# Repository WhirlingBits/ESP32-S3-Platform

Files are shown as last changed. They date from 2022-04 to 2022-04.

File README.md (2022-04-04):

# ESP_Platform_Schematic

## Description
Schematics of basic ESP32-S3-WROOM platform with versatile power management
for 12V and 5V supply and microSD card slot.
The board offers 2 USB-C receptables, one connecting to a USB-2-UART converter
(CP2102) feeding the genuine UART0 on ESP32-S3 and another directly connecting
to the ESP32-S3's USB OTG port.

## Power Management
The board may be powered by one of the USB ports (VBUS) or with an external
power supply connected via BarrelJack. So altogether there are 3 possible sources of
power, USB (PGM), USB (Data) and Ext. To prevent any currents flowing from the
source with higher voltage to a source with lower voltage Schotty diodes with
low treshold have been implemented.

Thanx to the buck/boost capability of the LTC3111 used the external power input
voltage may supply a voltage between 3..15V.

Alternatively it is possible to use an external battery controller (e.g. Sparkfun
Babysitter) which is connected on J5 whereas J5.4 (+5VD) will be the input for the
controller and J5.1,2 the output.

## Wifi/BT module from Espressif
For the module we have chosen an ESP32-S3-WROOM-1 from Espressif with 8MByte
serial FLASH and 8MByte PSRAM (suffix -N8R8). ESP32-S3 is more powerful than
classical ESP32-D0WD as its using Dual Core Tensilica LX7 with an augmented 
instruction set supporting low level calculations for CNN processing (tinyML).
For precision of all time related processes there's an clock crystal (32kHz)
assembled.

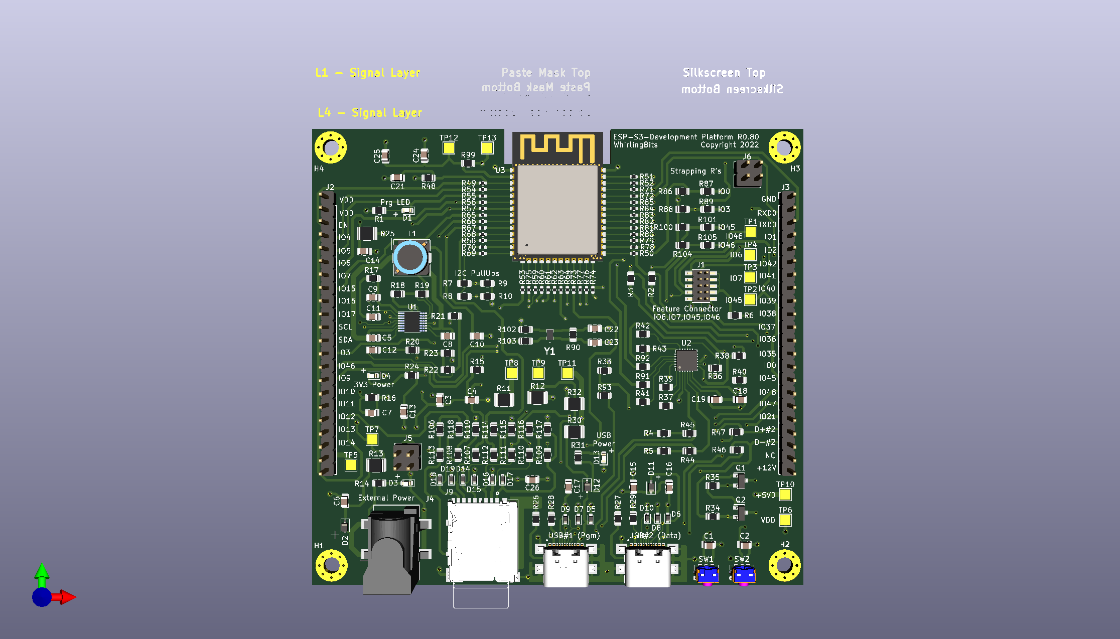
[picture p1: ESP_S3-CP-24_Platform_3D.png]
PCB-3D-View


And this is the real board:
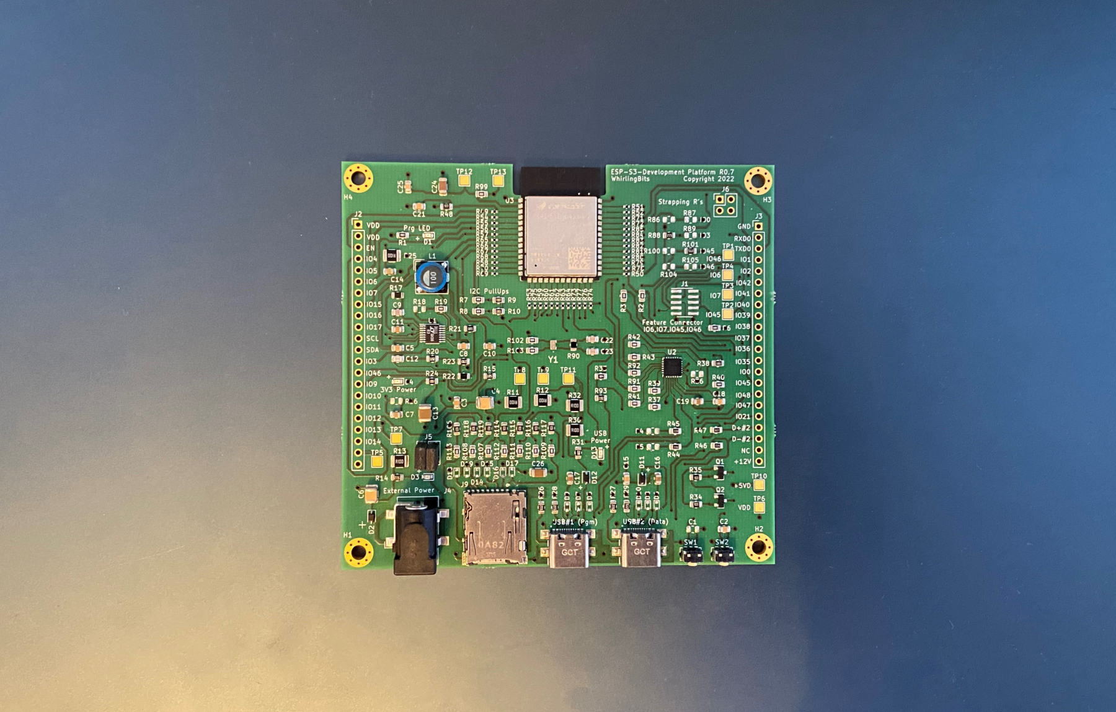
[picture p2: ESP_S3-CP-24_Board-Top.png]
PCB Mounted Board


## CAE System
Schematics and Layout have been developed using KiCAD 5.x version. You may
just download the complete repository to a folder inside your KiCAD project
directories to start using it.

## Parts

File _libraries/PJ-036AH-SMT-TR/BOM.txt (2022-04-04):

3DX_CUI_DEVICES_Supplier: CUI Devices
3DX_CUI_DEVICES_Description: 2.0 x 6.3 mm, 5.0 A, Horizontal, Surface Mount (SMT), Dc Power Jack Connector
3DX_CUI_DEVICES_Model Number: PJ-036AH-SMT-TR

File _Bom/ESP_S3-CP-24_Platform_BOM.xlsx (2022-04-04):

ESP-S3 Developer Platform R0.80 (12.3.2022)
Pos | Sourced | References | Value | Footprint | DigiKey | LCSC | Mouser | Quantity
1 |  | C2, C3, C5, C8, C15, C18, C21, C25 | 0.1uF, 50V | C_0805_2012Metric |  | C161260 |  | 8
2 |  | C7, C10, C14 | 1uF, 16V | C_0805_2012Metric |  | C16834 |  | 3
3 |  | C16, C17, C19 | 4.7uF, 25V | C_0805_2012Metric |  | C98192 |  | 3
4 |  | C4, C6 | 47uF, 22V | C_0805_2012Metric |  | C913559 |  | 2
5 |  | C22, C23 | 12pF, 50V | C_0805_2012Metric |  | C182488 |  | 2
6 |  | C24, C26 | 22uF, 10V | C_0805_2012Metric |  | C77074 |  | 2
7 |  | C1 | 0.1uF, 50V (DNP) | C_0805_2012Metric |  | C161260 |  | 1
8 |  | C9 | 22p | C_0805_2012Metric |  | C105623 |  | 1
9 |  | C11 | 1500p | C_0805_2012Metric |  | C114765 |  | 1
10 |  | C12 | 47p | C_0805_2012Metric |  | C113821 |  | 1
11 |  | C13 | 100uF, 6,3V | C_0805_2012Metric |  | C141660 |  | 1
12 |  | R49, R50, R51, R52, R53, R54, R55, R56, R57, R58, R59, R60, R61, R62, R63, R64, R65, R66, R67, R68, R69, R70, R71, R72, R73, R74, R75, R76, R77, R78, R79, R80, R81, R82, R83, R84, R85 | 22R | R_0402_1005Metric |  | C114765 |  | 37
13 |  | R2, R3, R6, R7, R8, R19, R37, R39, R40, R41, R42, R43, R91, R92, R99, R102, R103, R107, R108, R109, R110, R111, R112, R113 | 0R | R_0805_2012Metric |  | C100045 |  | 24
14 |  | R34, R35, R48, R106, R114, R115, R116, R117, R118, R119 | 10k | R_0805_2012Metric |  | C169253 |  | 10
15 |  | R14, R26, R27, R28, R29, R88, R101 | 5k1 | R_0805_2012Metric |  | C204548 |  | 7
16 |  | R11, R12, R13, R25, R30, R32 | 0R1 | R_1210_3225Metric |  | C473589 |  | 6
17 |  | R86, R87, R89, R100, R104, R105 | 5k1 (DNP) | R_0805_2012Metric |  | C204548 |  | 6
18 |  | R44, R45, R46, R47 | 22R | R_0805_2012Metric |  | C144531 |  | 4
19 |  | R4, R5, R16 | 1M (DNP) | R_0805_2012Metric |  | C230655 |  | 3
20 |  | R9, R10, R38 | 1k | R_0805_2012Metric |  | C95781, |  | 3
21 |  | R1 | 1k8 | R_0805_2012Metric |  | C137465 |  | 1
22 |  | R15 | 1M | R_0805_2012Metric |  | C230655 |  | 1
23 |  | R17 | 41,2k | R_0805_2012Metric |  | C204486 |  | 1
24 |  | R18 | 0R (DNP) | R_0805_2012Metric |  | C100045 |  | 1
25 |  | R20 | 11,5k | R_0805_2012Metric |  | C228269 |  | 1
26 |  | R21 | 49R9 | R_0805_2012Metric |  | C479104 |  | 1
27 |  | R22 | 845k | R_0805_2012Metric |  | C416871 |  | 1
28 |  | R23 | 270k | R_0805_2012Metric |  | C352236 |  | 1
29 |  | R24 | 1k5 | R_0805_2012Metric |  | C163951 |  | 1
30 |  | R31 | 2k2 | R_0805_2012Metric |  | C441982 |  | 1
31 |  | R33 | 47.5k | R_0805_2012Metric |  | C104355 |  | 1
32 |  | R36 | 10k (DNP) | R_0805_2012Metric |  |  |  | 1
33 |  | R90 | 5.6M | R_0805_2012Metric |  | C185285 |  | 1
34 |  | R93 | 22.1k | R_0805_2012Metric |  | C104113 |  | 1
35 |  | L1 | 10uH - SLF7032T-100M1R4-2PF | L_TDK_SLF7032 |  | C76852 |  | 1
36 |  | D5, D6, D7, D8, D9, D10, D14, D15, D16, D17, D18, D19 | PESD15VW1BCSFYL | D_SOD-523 |  |  | 771-PESD15VW1BCSFYL | 12
37 |  | D1, D3, D4, D13 | LTST-C191KRKT (Red) | LED_0603_1608Metric |  | C125099 |  | 4
38 |  | D2, D11, D12 | BAT760-7 | D_SOD-323 |  | C116158 |  | 3
39 |  | U1 | LTC3111EMSEPBF | MSOP-16 |  | C684080 | 584-LTC3111EMSETRPBF | 1
40 |  | U2 | CP2102N-A02-GQFN24 | QFN-24-1EP_4x4mm_P0.5mm_EP2.6x2.6mm |  | C80225 |  | 1
41 |  | U3 | ESP32-S3-WROOM-1 | ESP32-S3-WROOM-1 |  | C2913201 |  | 1
42 |  | Y1 | XTAL 32,678kHz (C20S-12.5PF20PPM) | SC20S125PF20PPM |  | C97603 |  | 1
43 |  | SW1, SW2 | SKRTLAE010 | SW_Push_1P1T-MP_NO_Horizontal_Alps_SKRTLAE010 |  | C110293 |  | 2
44 |  | Q1, Q2 | SS8050-G | SOT-23 |  | C164885 |  | 2
45 |  | J2, J3 | Conn_01x22 (DNP) | PinHeader_1x22_P2.54mm_Vertical |  | C725954 |  | 2
46 |  | J5, J6 | Conn_02x02_Top_Bottom (DNP) | PinHeader_2x02_P2.54mm_Vertical |  | C492419 |  | 2
47 |  | J7, J8 | USB_C_Receptacle (USB4110-GF-A) | GCT_USB4110-GF-A_REVB |  |  | 640-USB4110-GF-A | 2
48 |  | J1 | Conn_02x05_Odd_Even | PinHeader_2x05_P1.27mm_Vertical_SMD |  | C150517 |  | 1
49 |  | J4 | PJ-002AH-SMT-TR (Barrel Jack) | BarrelJack_CLIFF_FC681465S_SMT_Horizontal |  |  | 490-PJ-002AH-SMT-TR | 1
50 |  | J9 | DM3AT-SF-PEJM5 | HRS_DM3AT-SF-PEJM5 |  | C114218 |  | 1

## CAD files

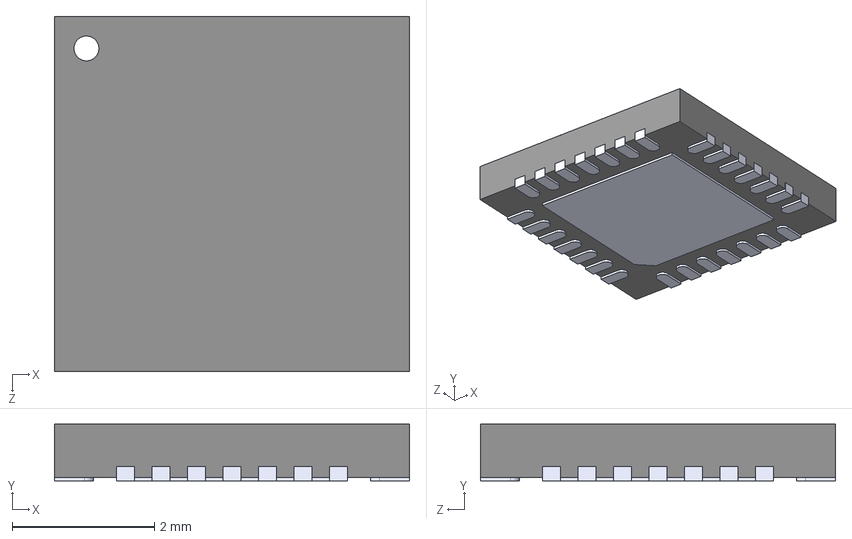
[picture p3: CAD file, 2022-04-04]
_libraries/CP2102N-A01-GQFN28/CP2102N-A01-GQFN28.step
5.00 x 0.8 x 5.00 mm

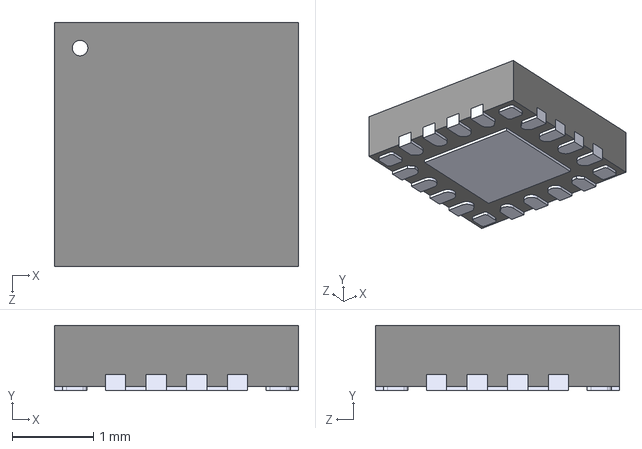
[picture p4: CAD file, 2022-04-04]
_libraries/CP2102N-A02-GQFN20R/CP2102N-A02-GQFN20R.step
3.00 x 0.8 x 3.00 mm

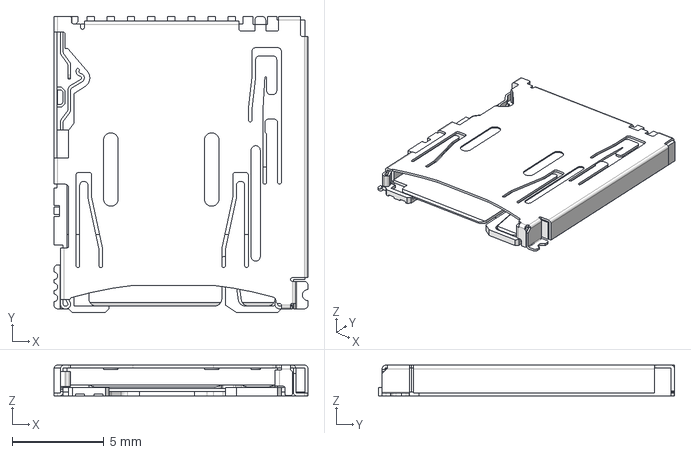
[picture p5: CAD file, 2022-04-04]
_libraries/DM3AT-SF-PEJM5/DM3AT-SF-PEJM5.step
13.8 x 16.2 x 1.68 mm

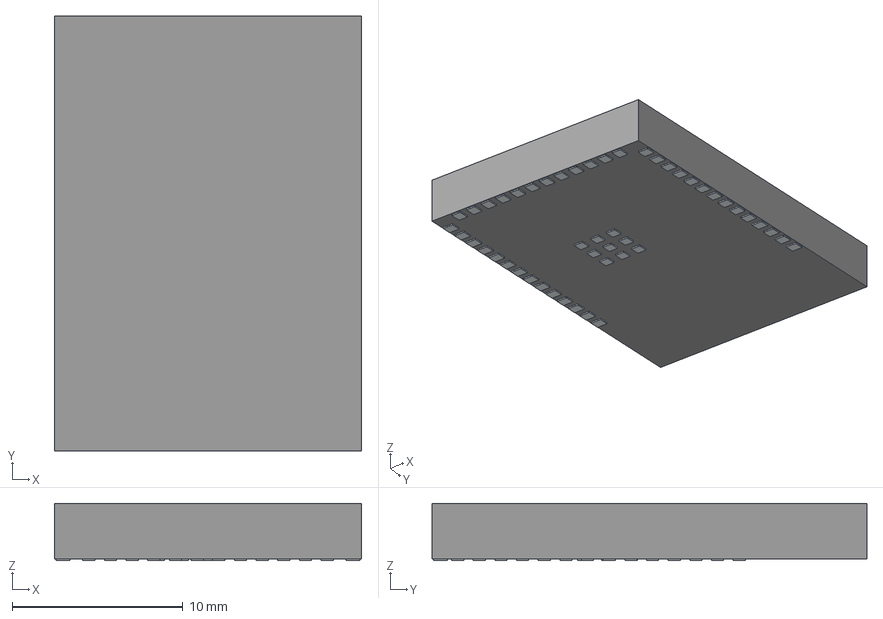
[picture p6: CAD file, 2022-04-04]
_libraries/ESP32-S3-WROOM/ESP32-S3-WROOM-1-N8R2.step
18.0 x 25.5 x 3.35 mm
Pins

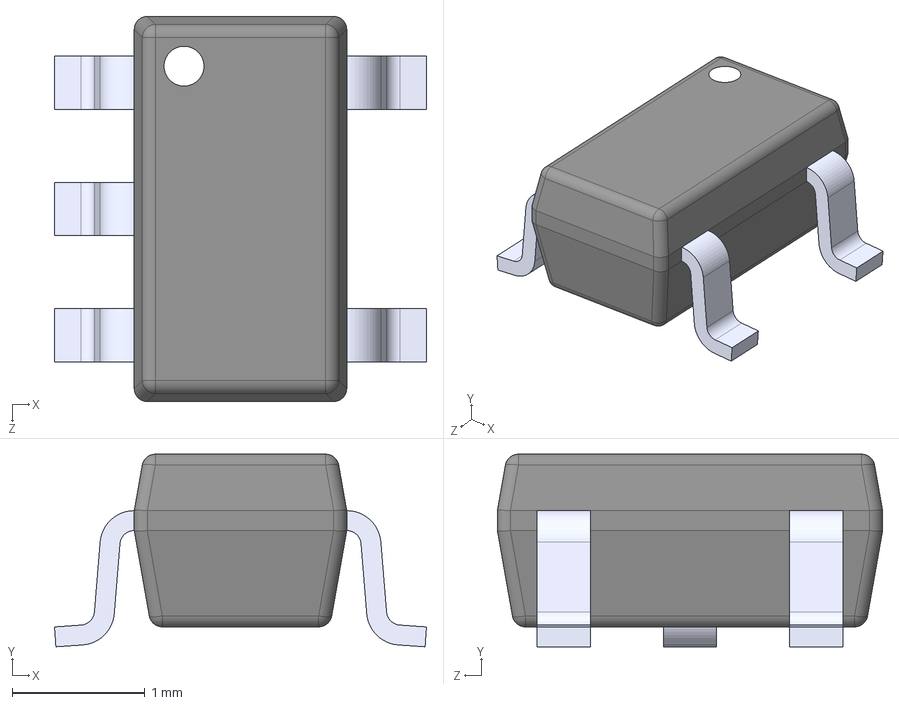
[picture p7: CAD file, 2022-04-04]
_libraries/LM3671MF-3.3/LM3671MF-3.3.step
2.80 x 1.45 x 2.90 mm

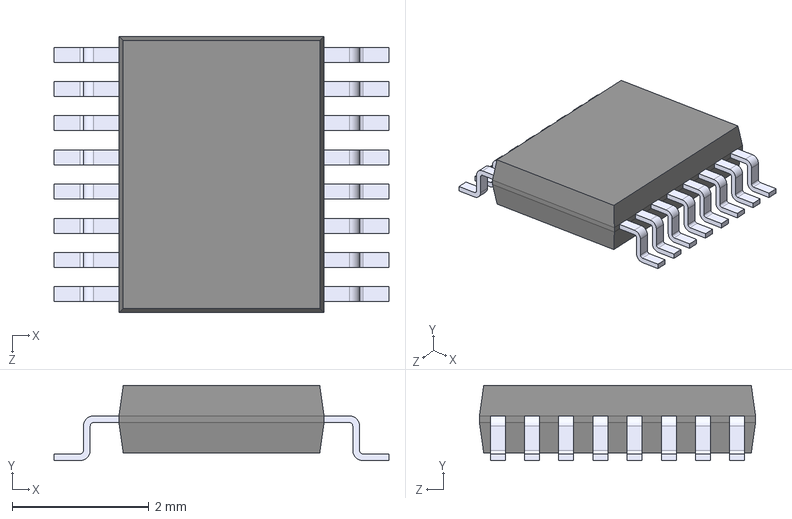
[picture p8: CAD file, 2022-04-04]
_libraries/LTC3111EMSEPBF/LTC3111EMSEPBF.step
4.90 x 1.10 x 4.04 mm

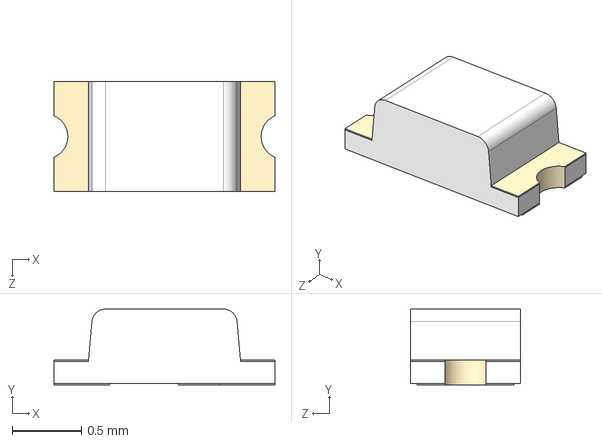
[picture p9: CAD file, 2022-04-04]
_libraries/LTST-C191KGKT/LTST-C191KGKT--3DModel-STEP-56544.STEP
1.60 x 0.55 x 0.8 mm

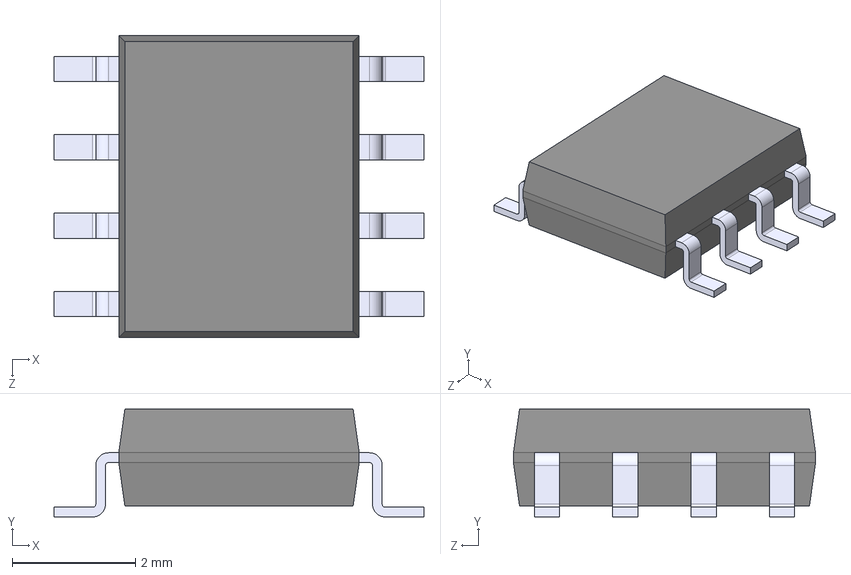
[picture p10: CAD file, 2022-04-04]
_libraries/MIC2026A-1YM-TR/MIC2026A-1YM-TR.step
6.00 x 1.75 x 4.90 mm

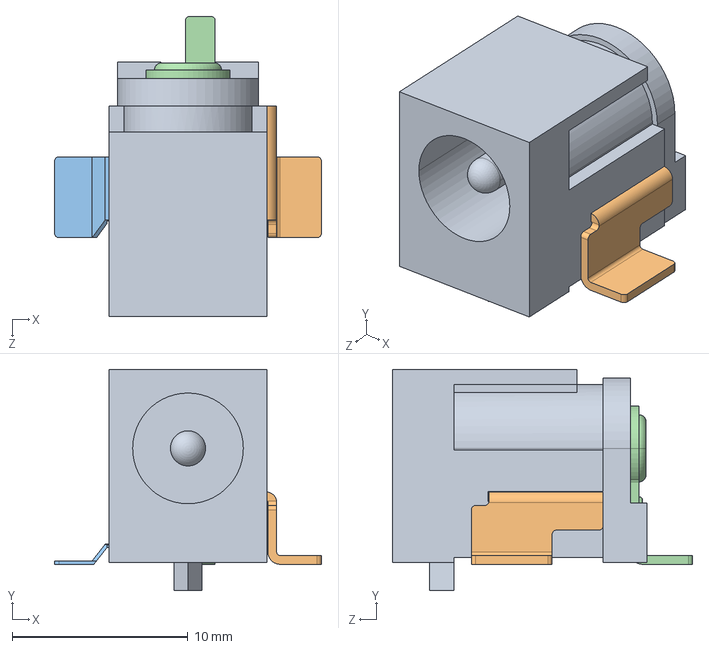
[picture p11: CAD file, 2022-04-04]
_libraries/PJ-036AH-SMT-TR/CUI_DEVICES_PJ-036AH-SMT-TR.step
15.2 x 12.6 x 17.1 mm

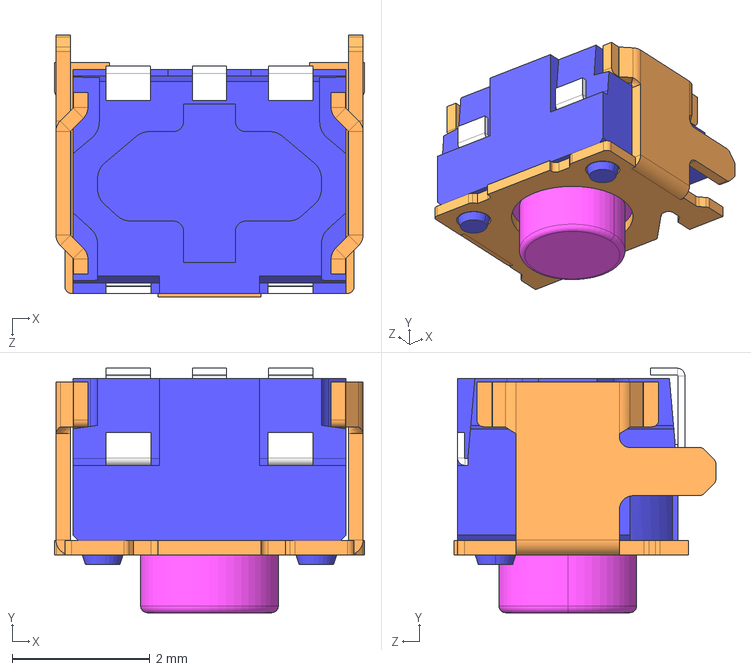
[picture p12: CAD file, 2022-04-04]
_libraries/SKRTLAE010/SKRTLA.STEP
4.50 x 3.55 x 3.80 mm

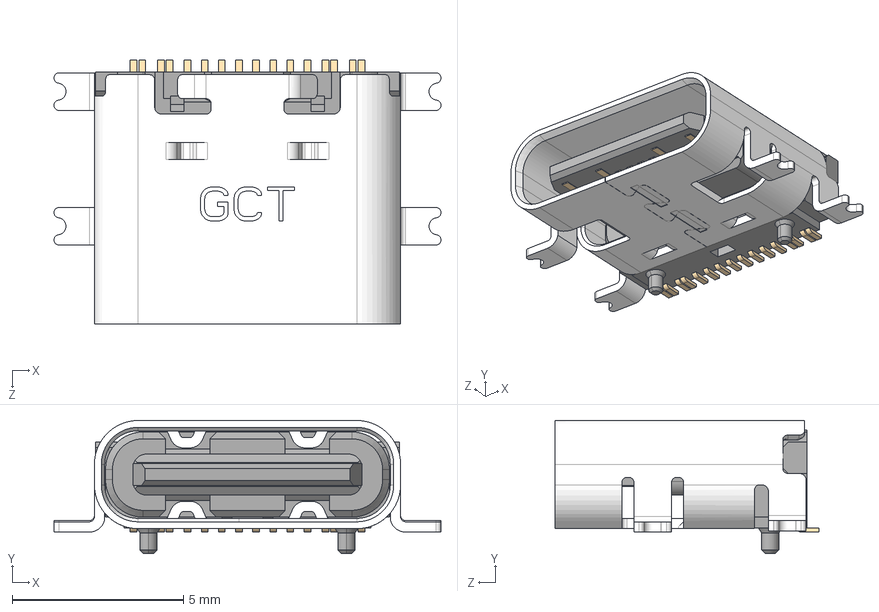
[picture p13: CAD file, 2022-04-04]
_libraries/USB4110-GF-A_REVB/USB4110-GF-A_REVB.step
11.3 x 3.89 x 7.70 mm

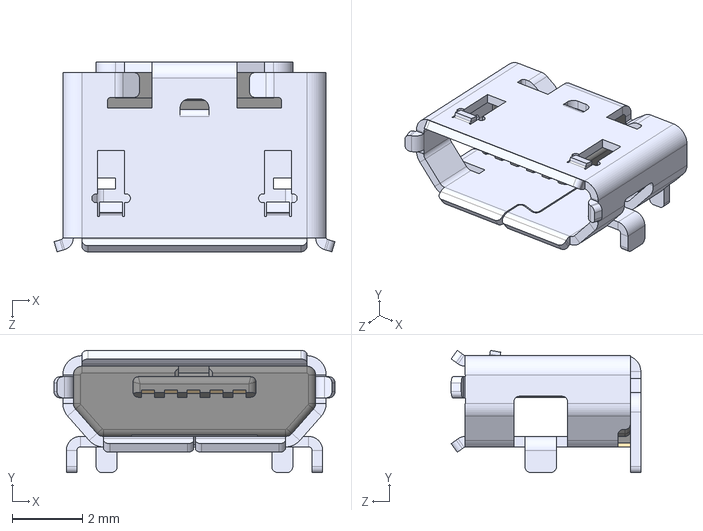
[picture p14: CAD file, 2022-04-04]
_libraries/105017-0001/105017-0001.step
8.00 x 3.48 x 5.40 mm

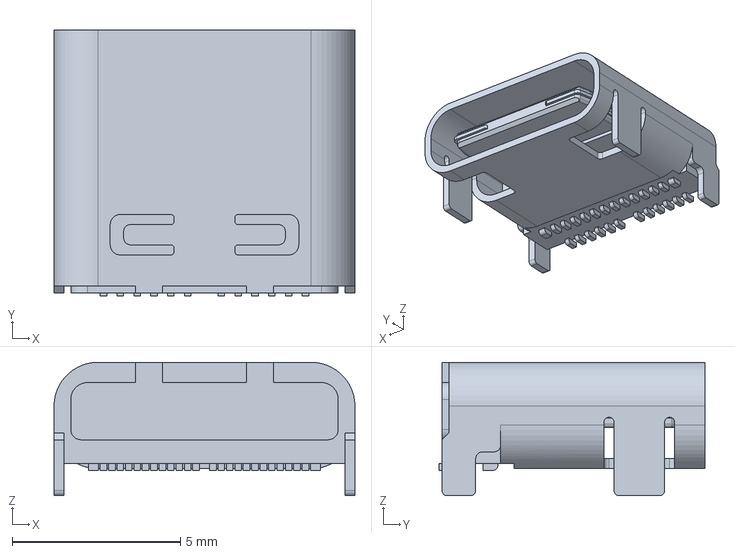
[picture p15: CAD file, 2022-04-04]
_libraries/1054500101 (Molex)/1054500101.step
8.94 x 7.90 x 3.96 mm

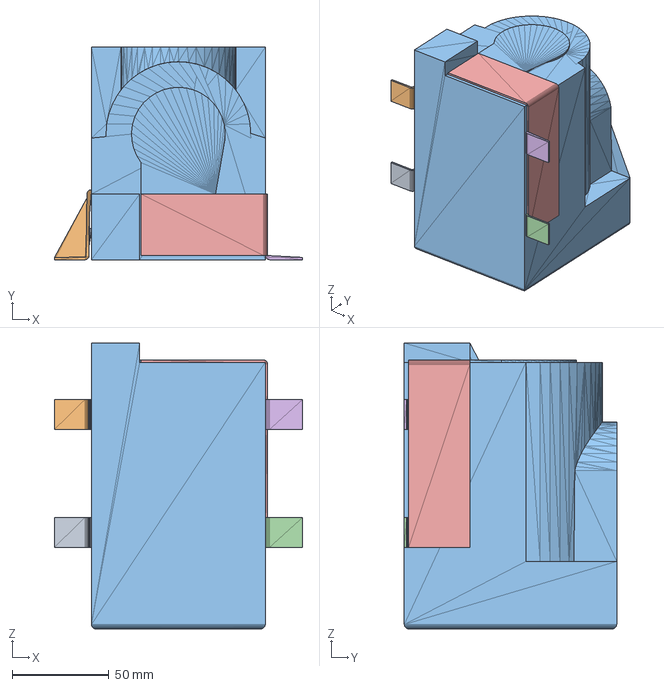
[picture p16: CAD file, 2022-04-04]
_libraries/DCBarrelPowerJAck_SMD/12748.step
128.4 x 110.0 x 148.0 mm

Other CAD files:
_libraries/ESP32-S3-WROOM/ESP32-S3-WROOM-1-N8R2.stl

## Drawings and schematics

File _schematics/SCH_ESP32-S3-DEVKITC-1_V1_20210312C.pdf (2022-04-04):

# System Block:

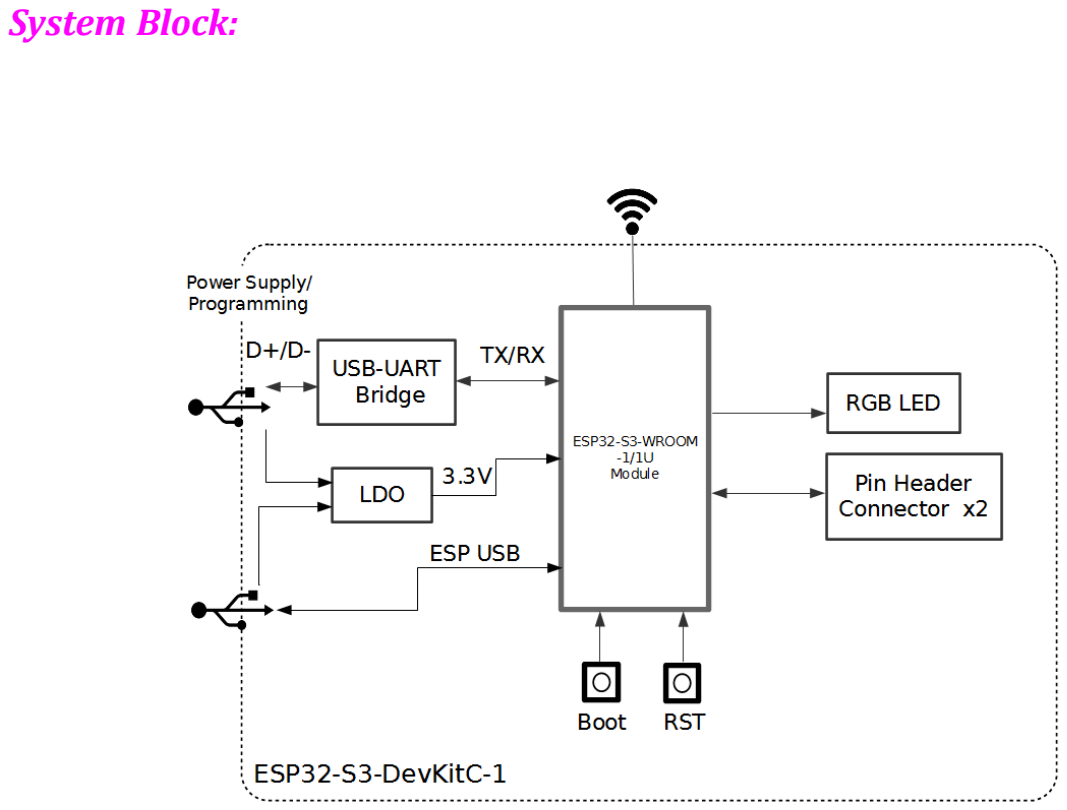
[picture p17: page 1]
Title; Size; Document Number; Rev; Date:; Sheet; <01_DesignBlock>; ESP32-S3-DevKitC-1; Friday, March 12, 2021

# USB to UART:

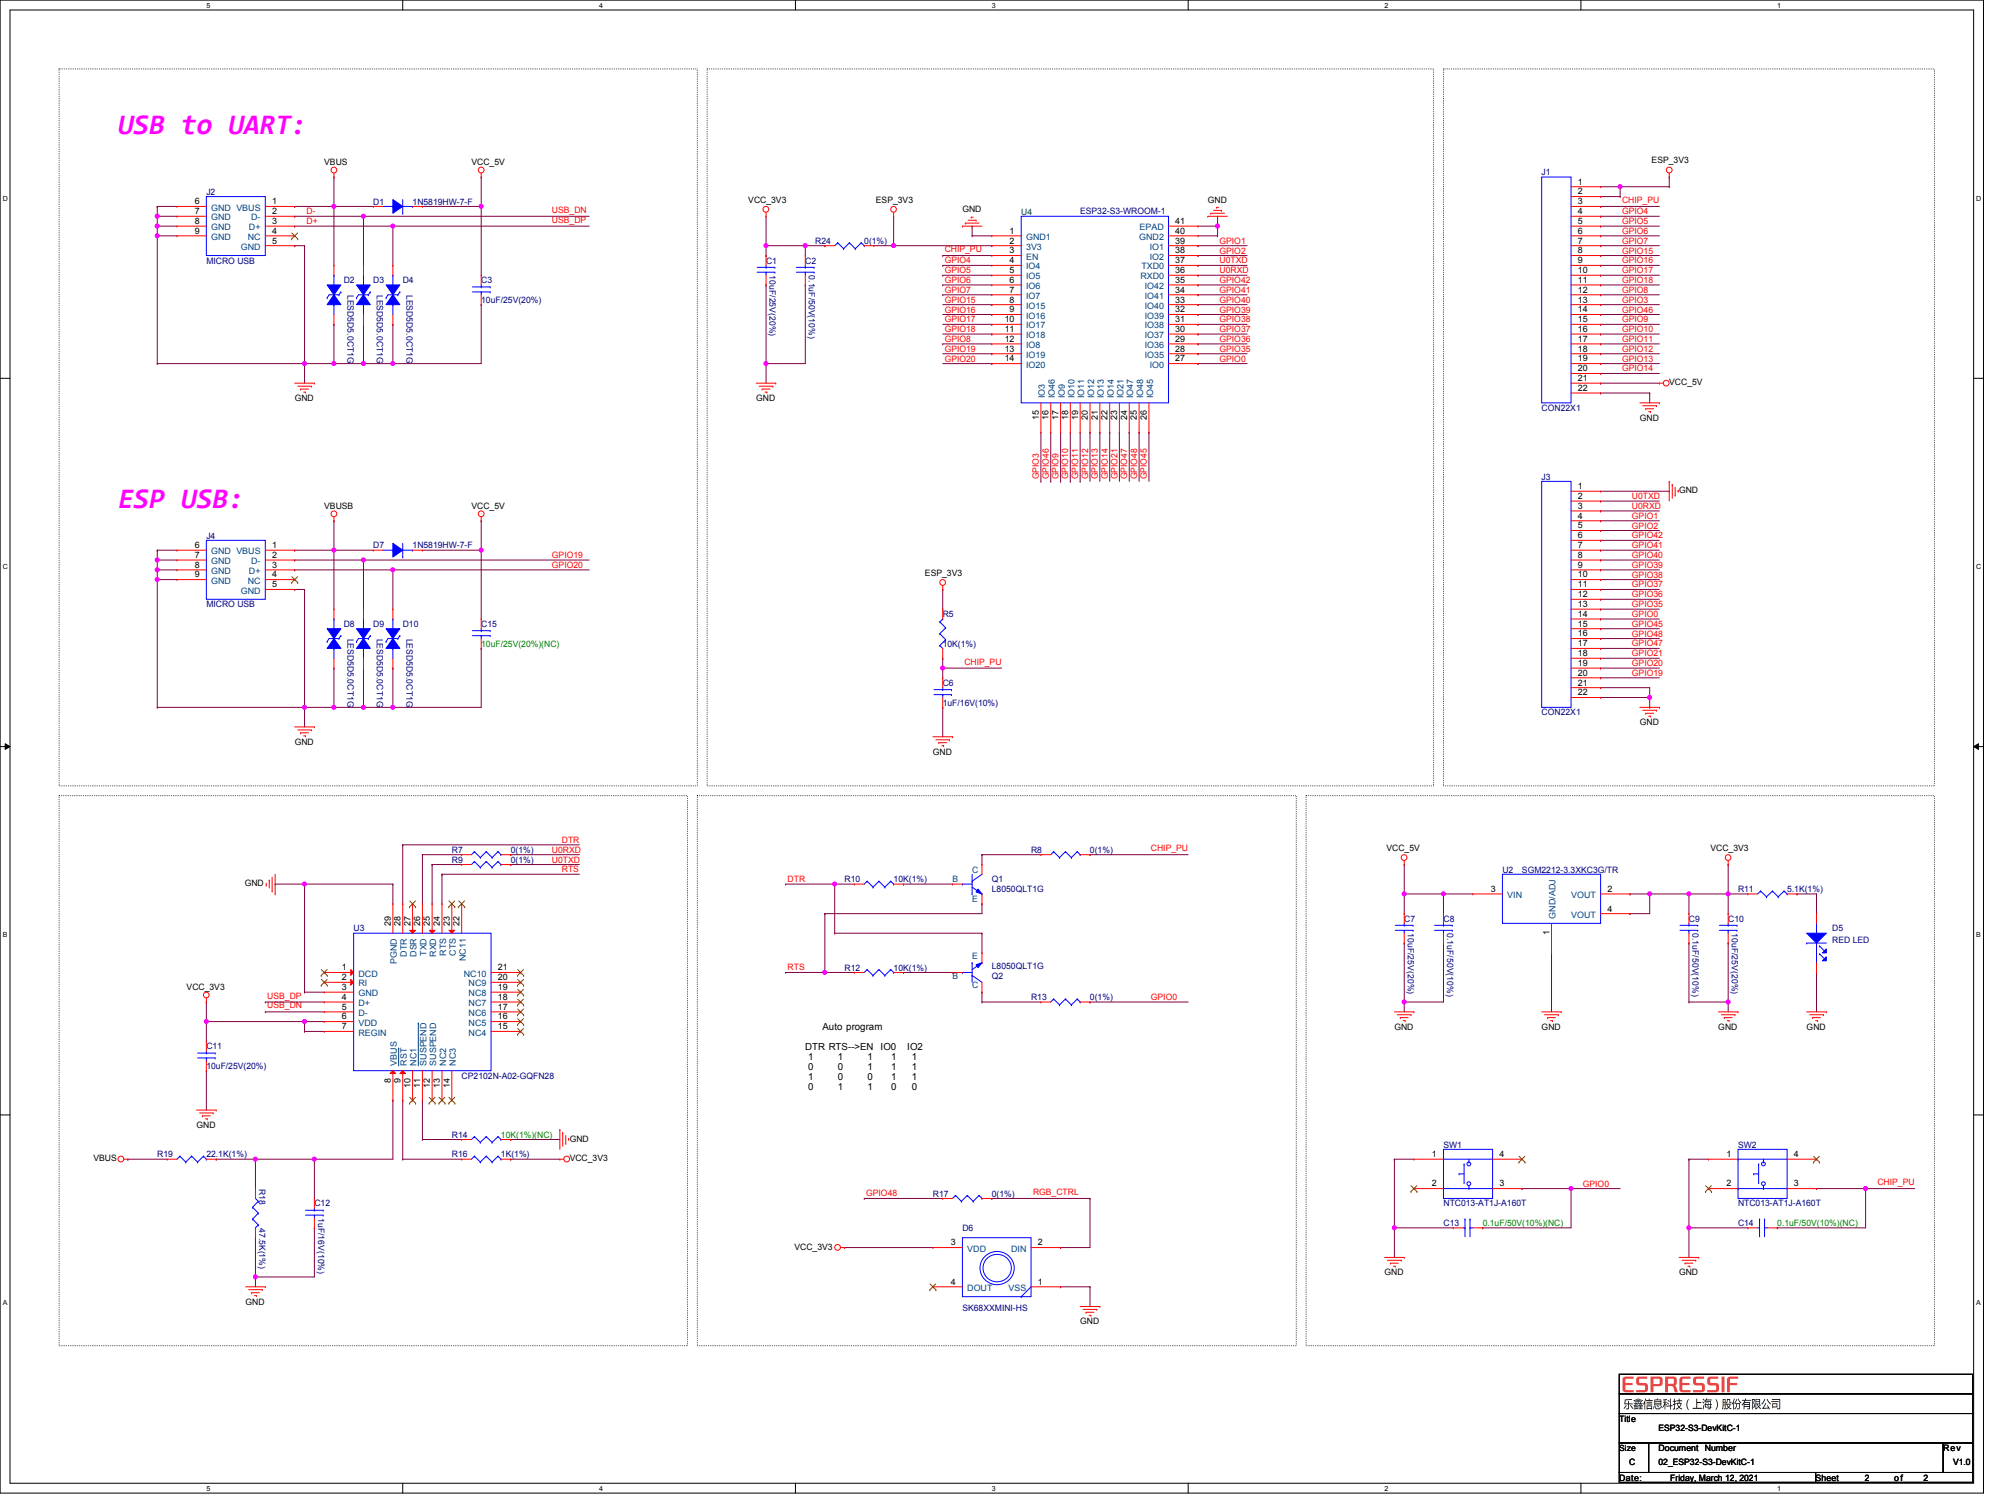
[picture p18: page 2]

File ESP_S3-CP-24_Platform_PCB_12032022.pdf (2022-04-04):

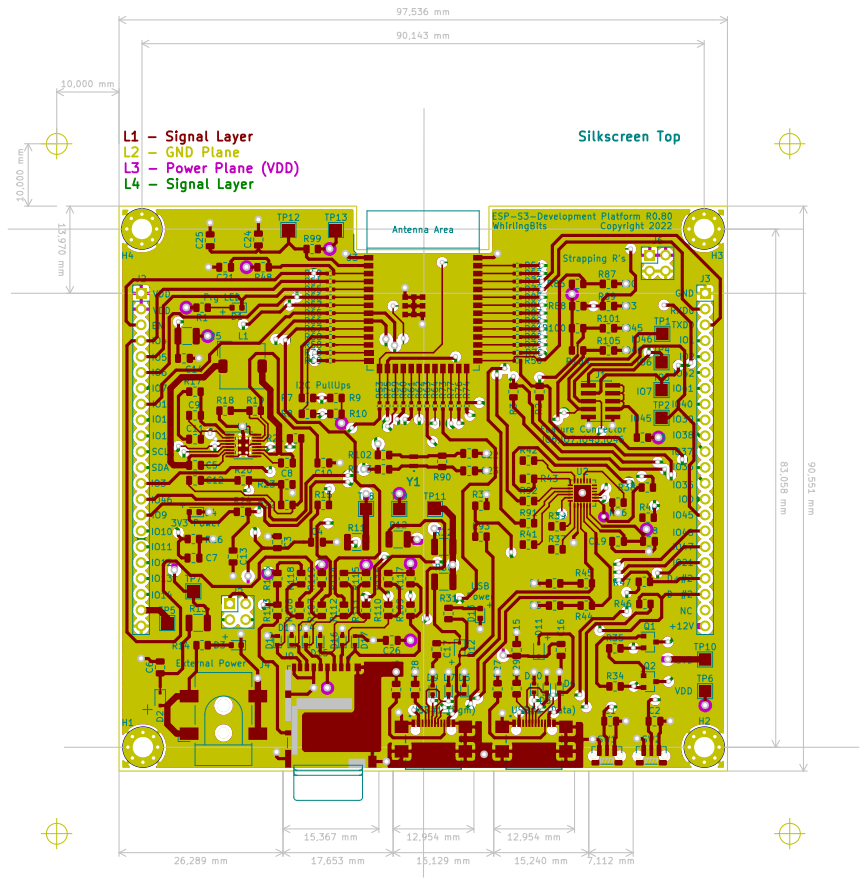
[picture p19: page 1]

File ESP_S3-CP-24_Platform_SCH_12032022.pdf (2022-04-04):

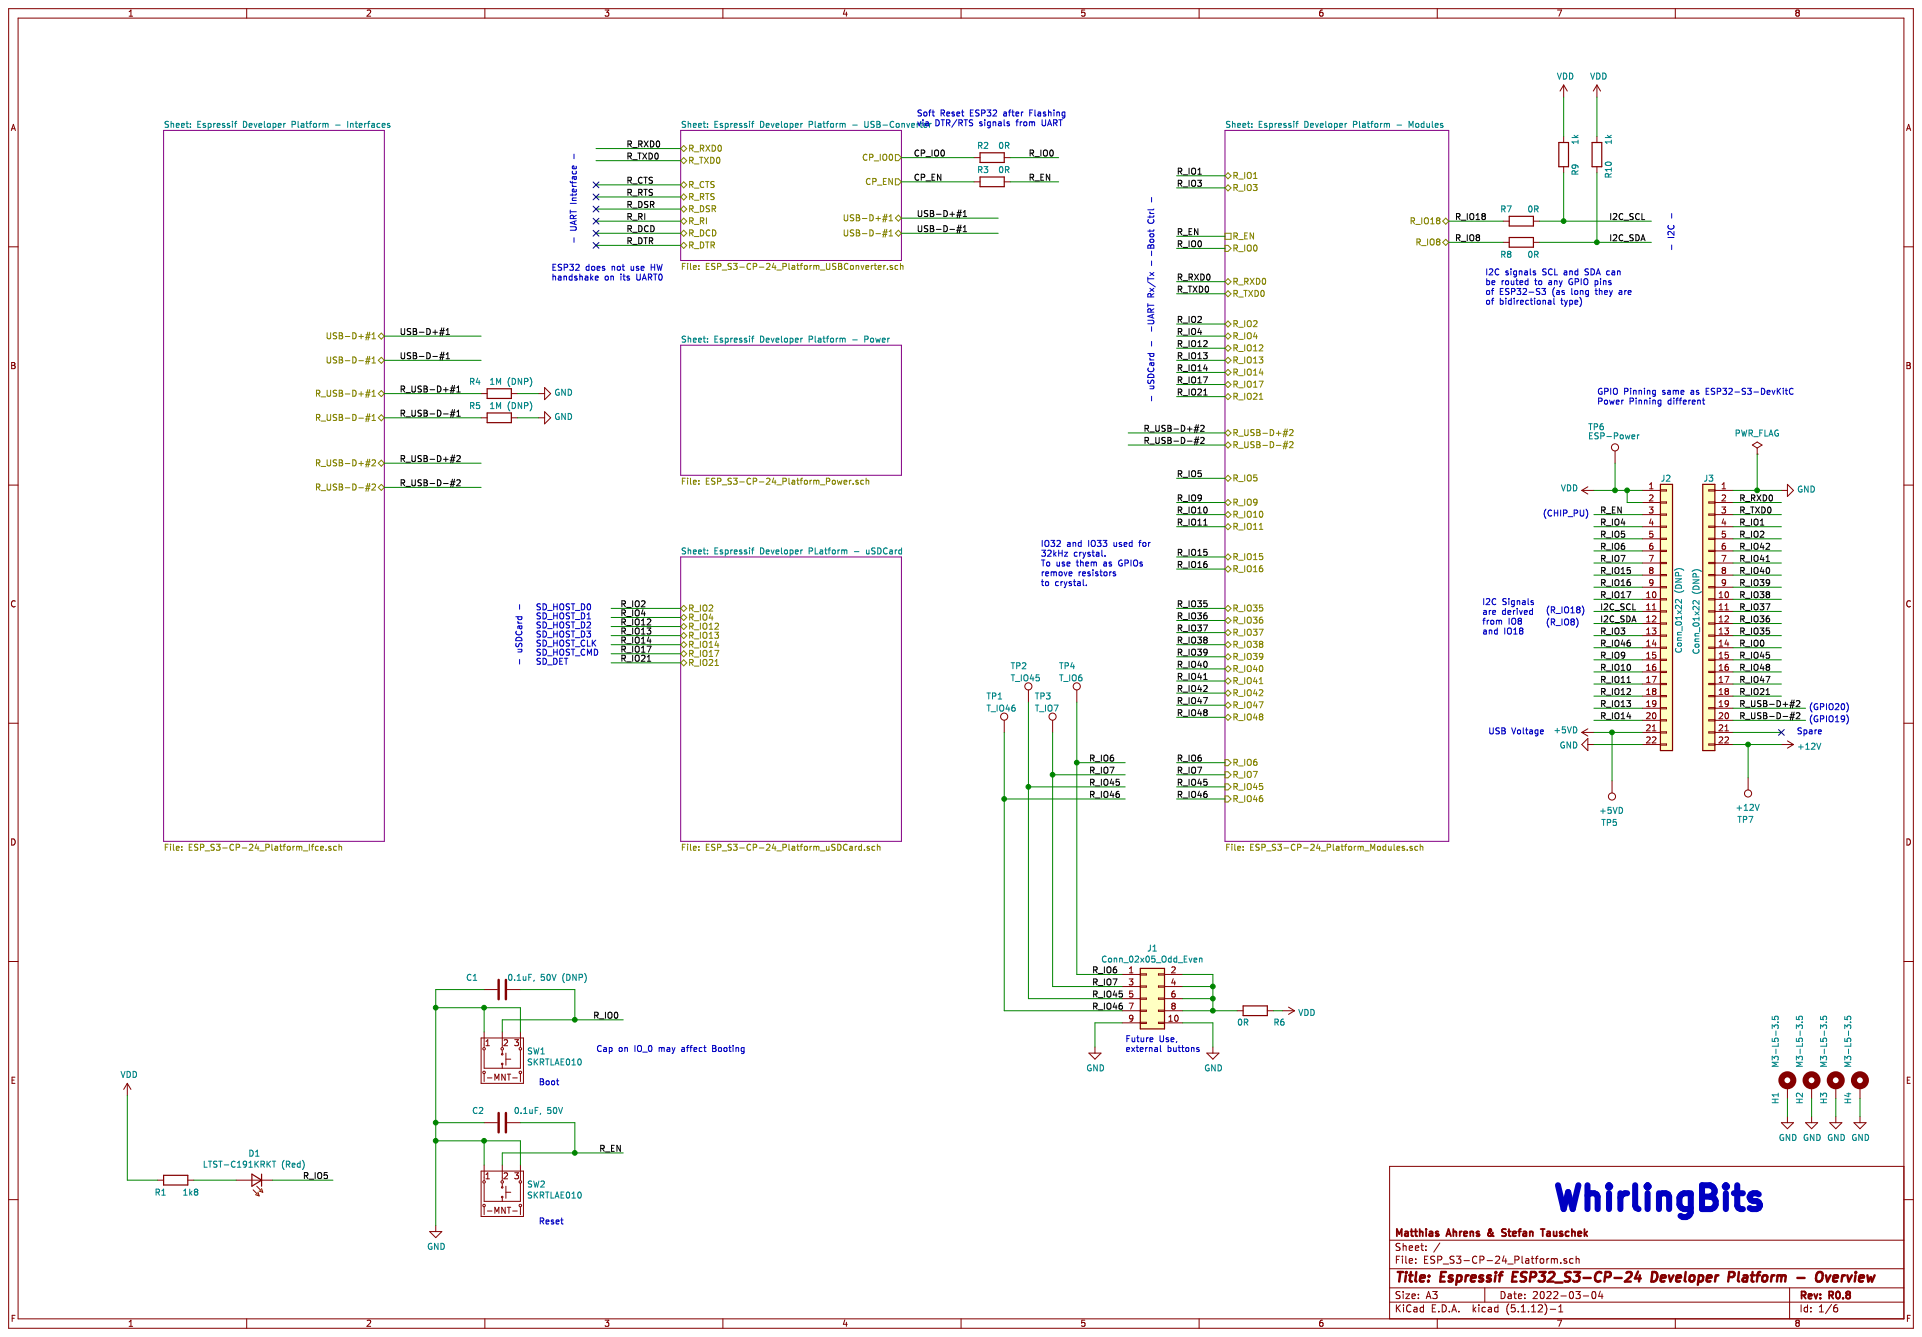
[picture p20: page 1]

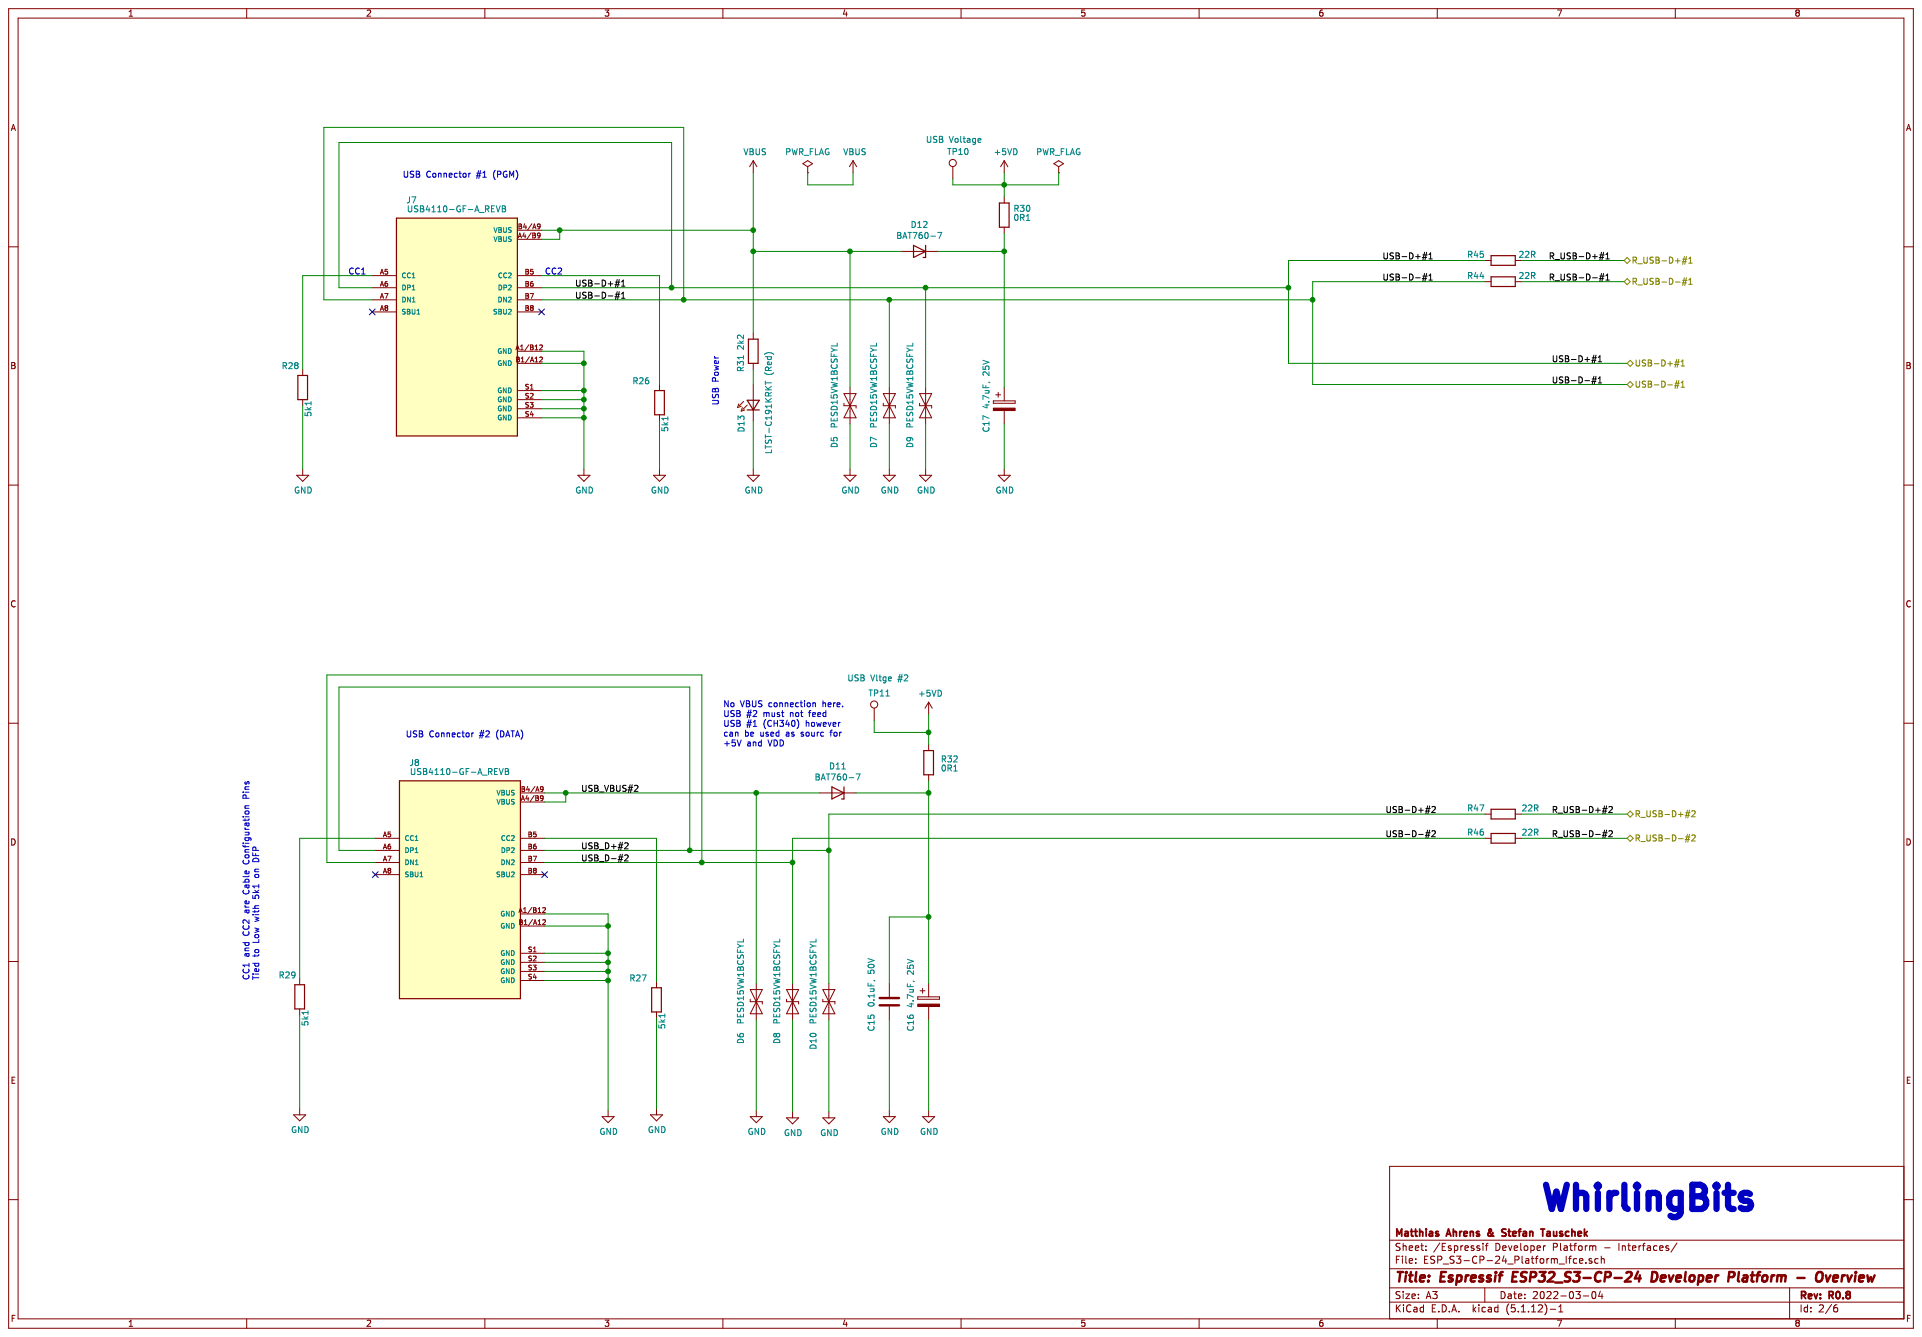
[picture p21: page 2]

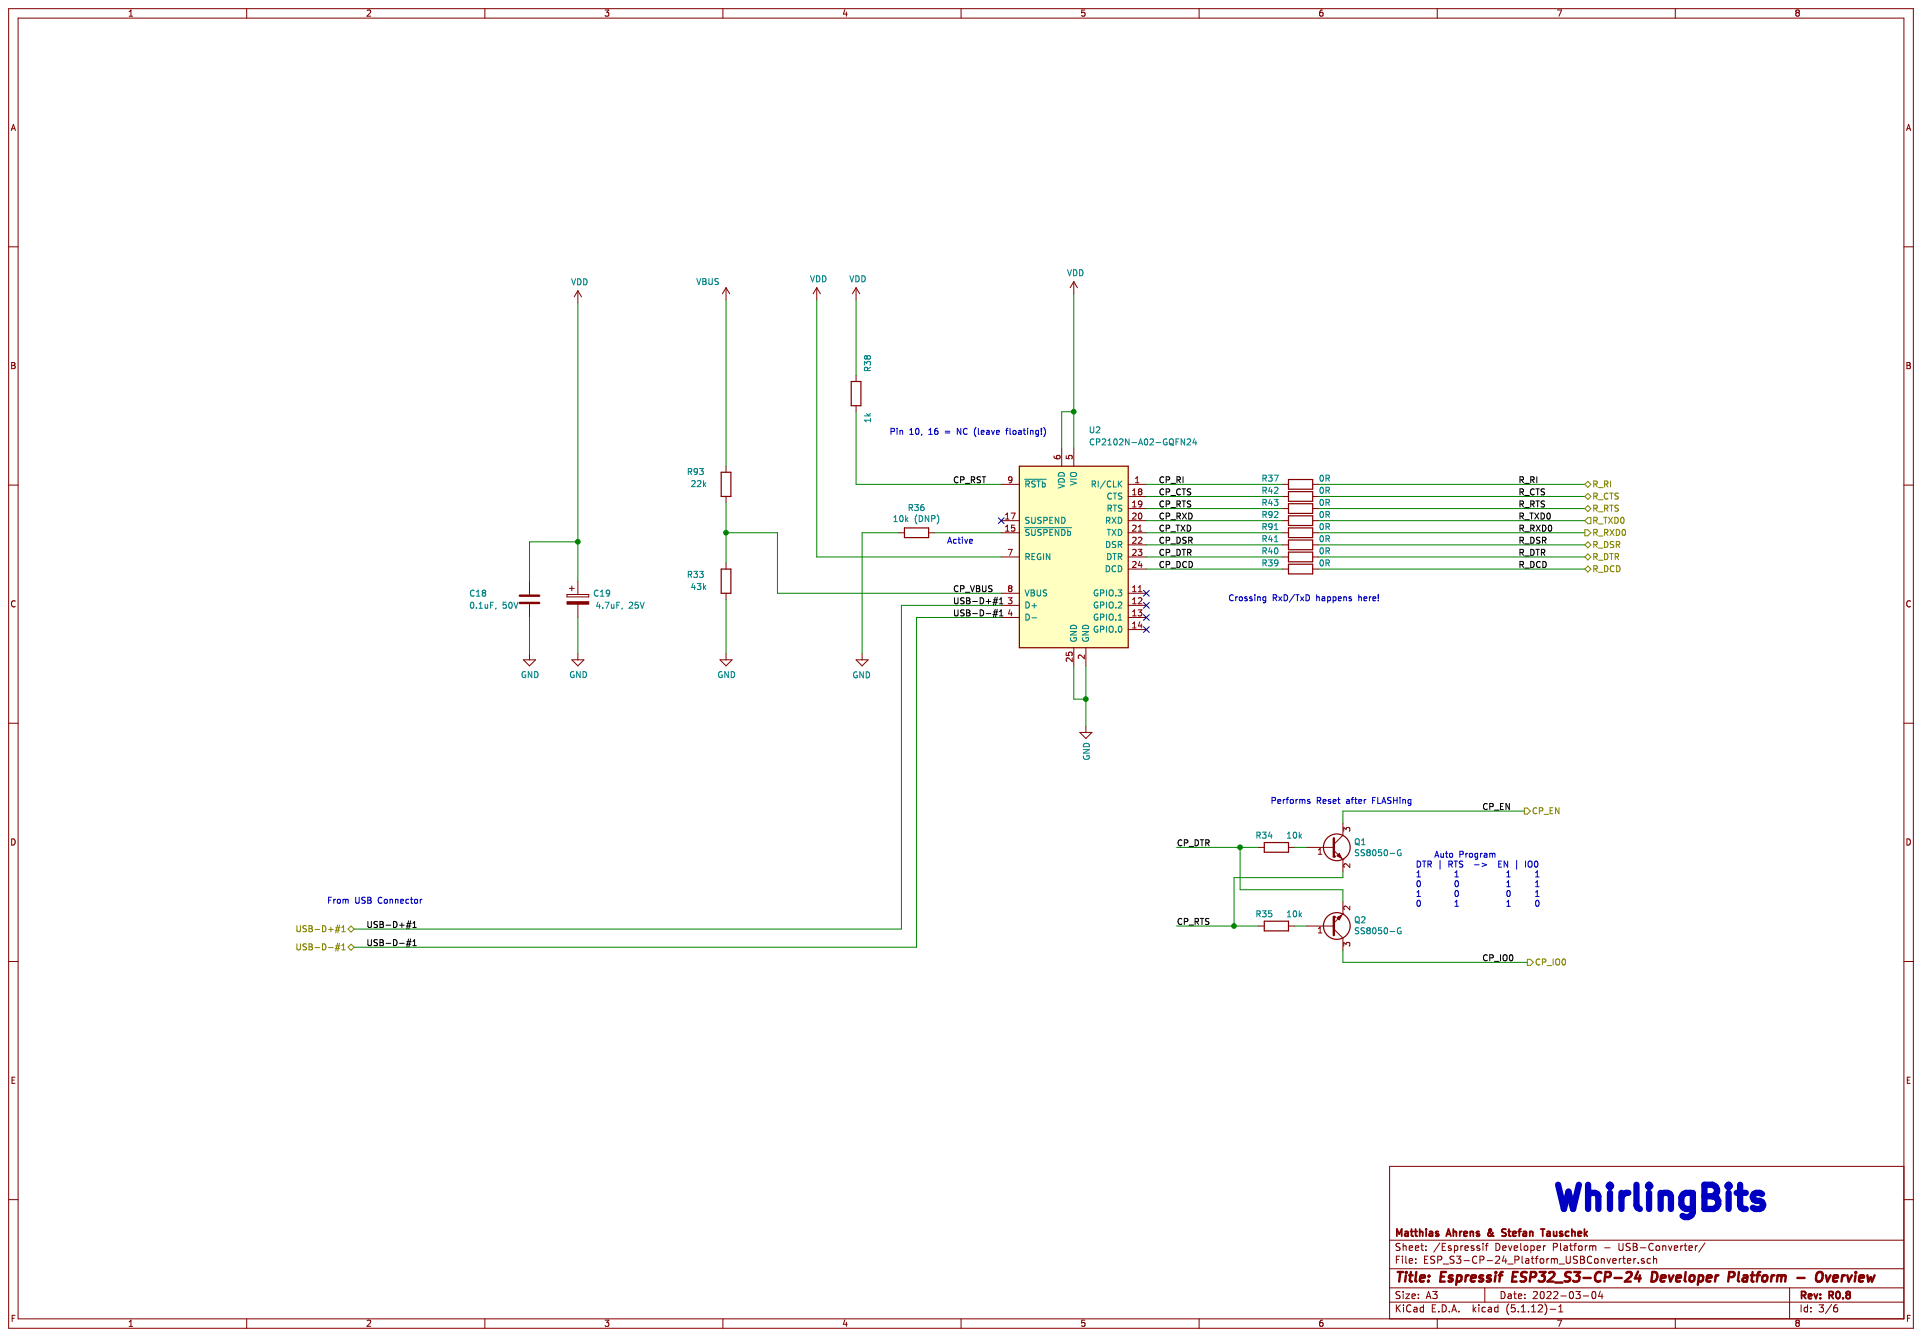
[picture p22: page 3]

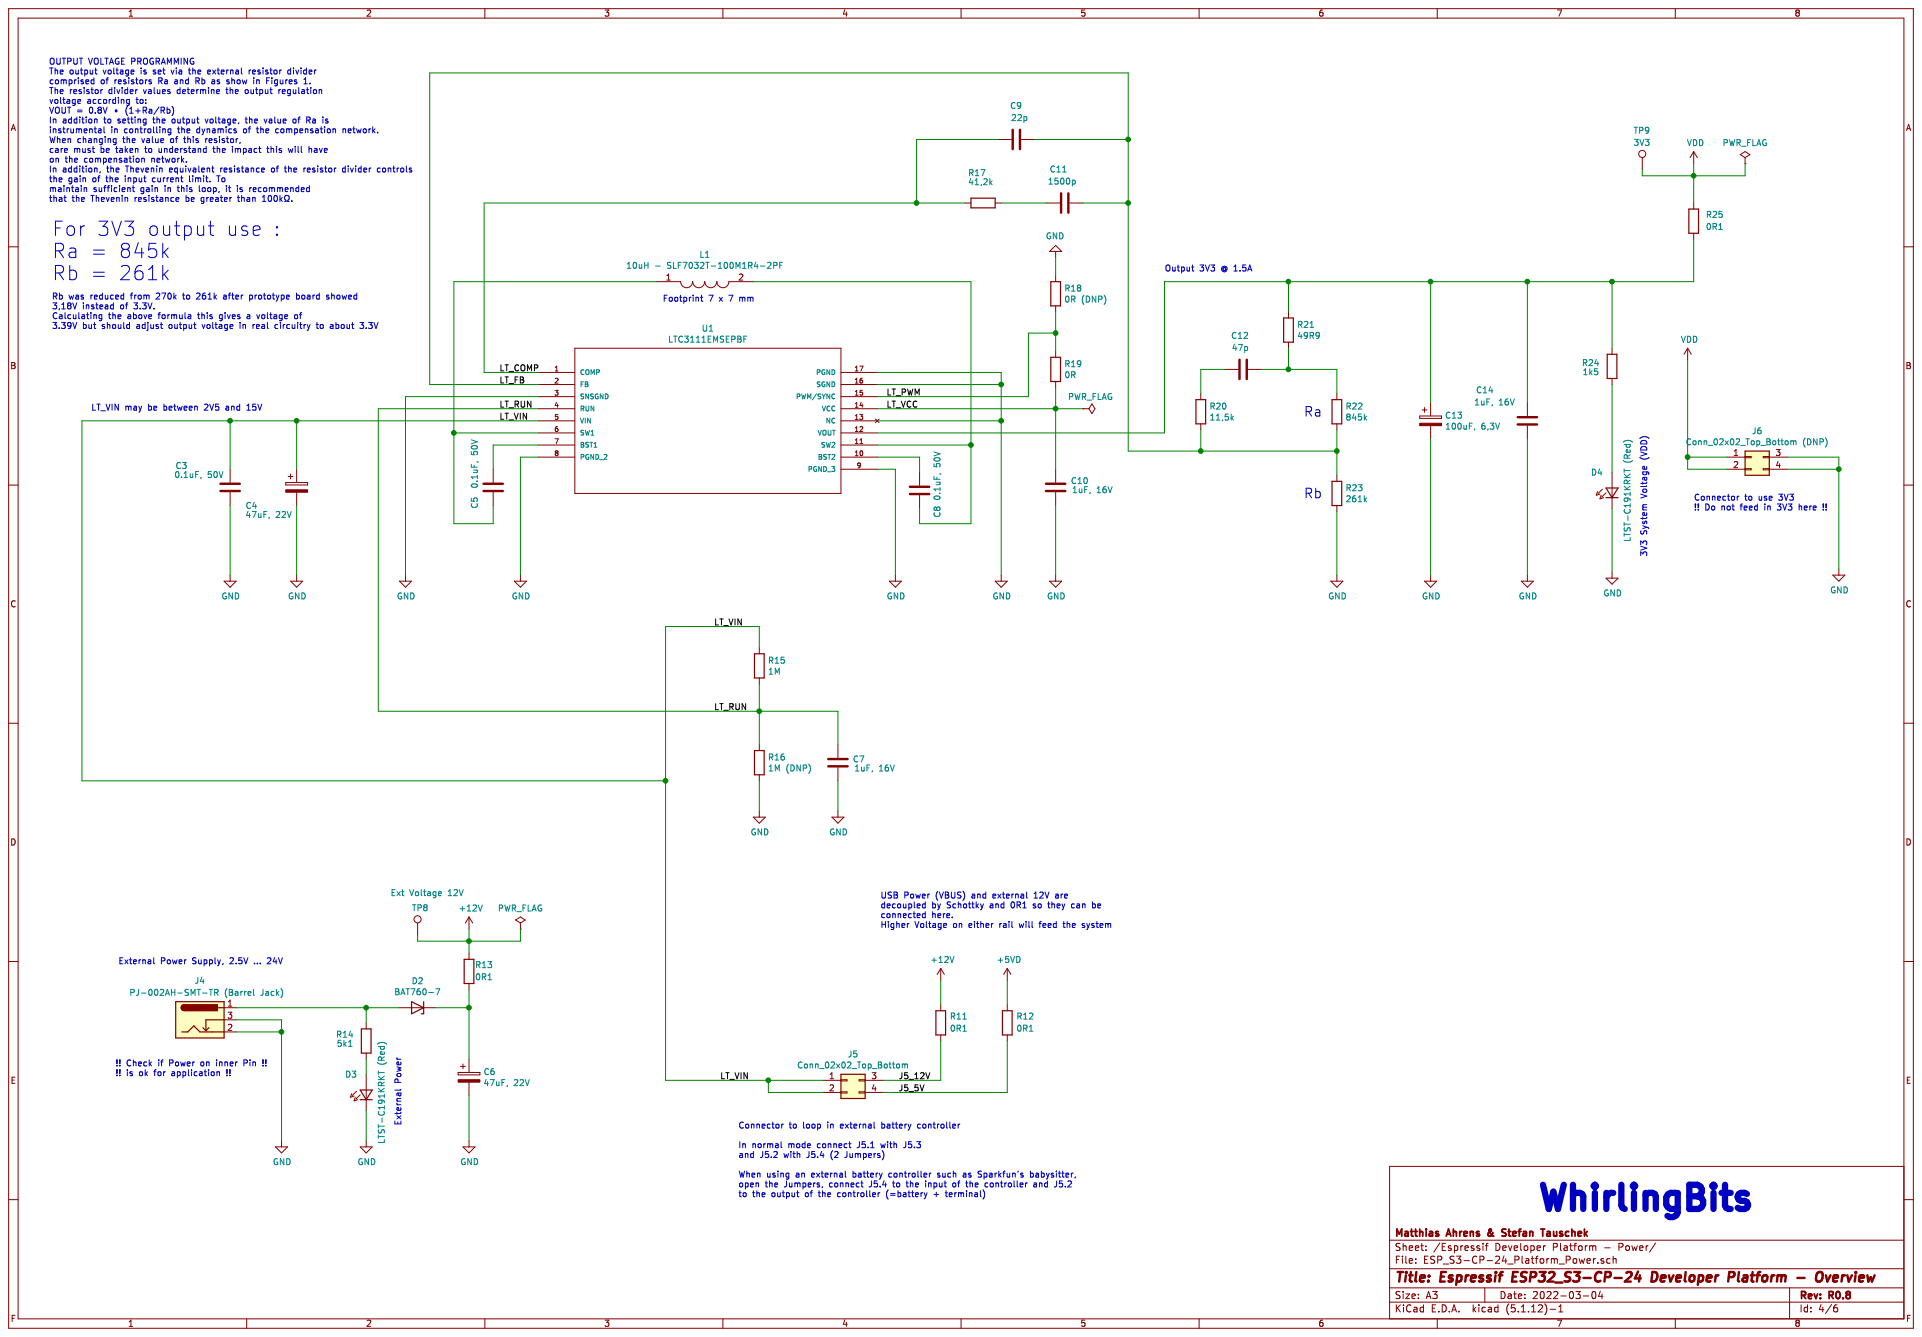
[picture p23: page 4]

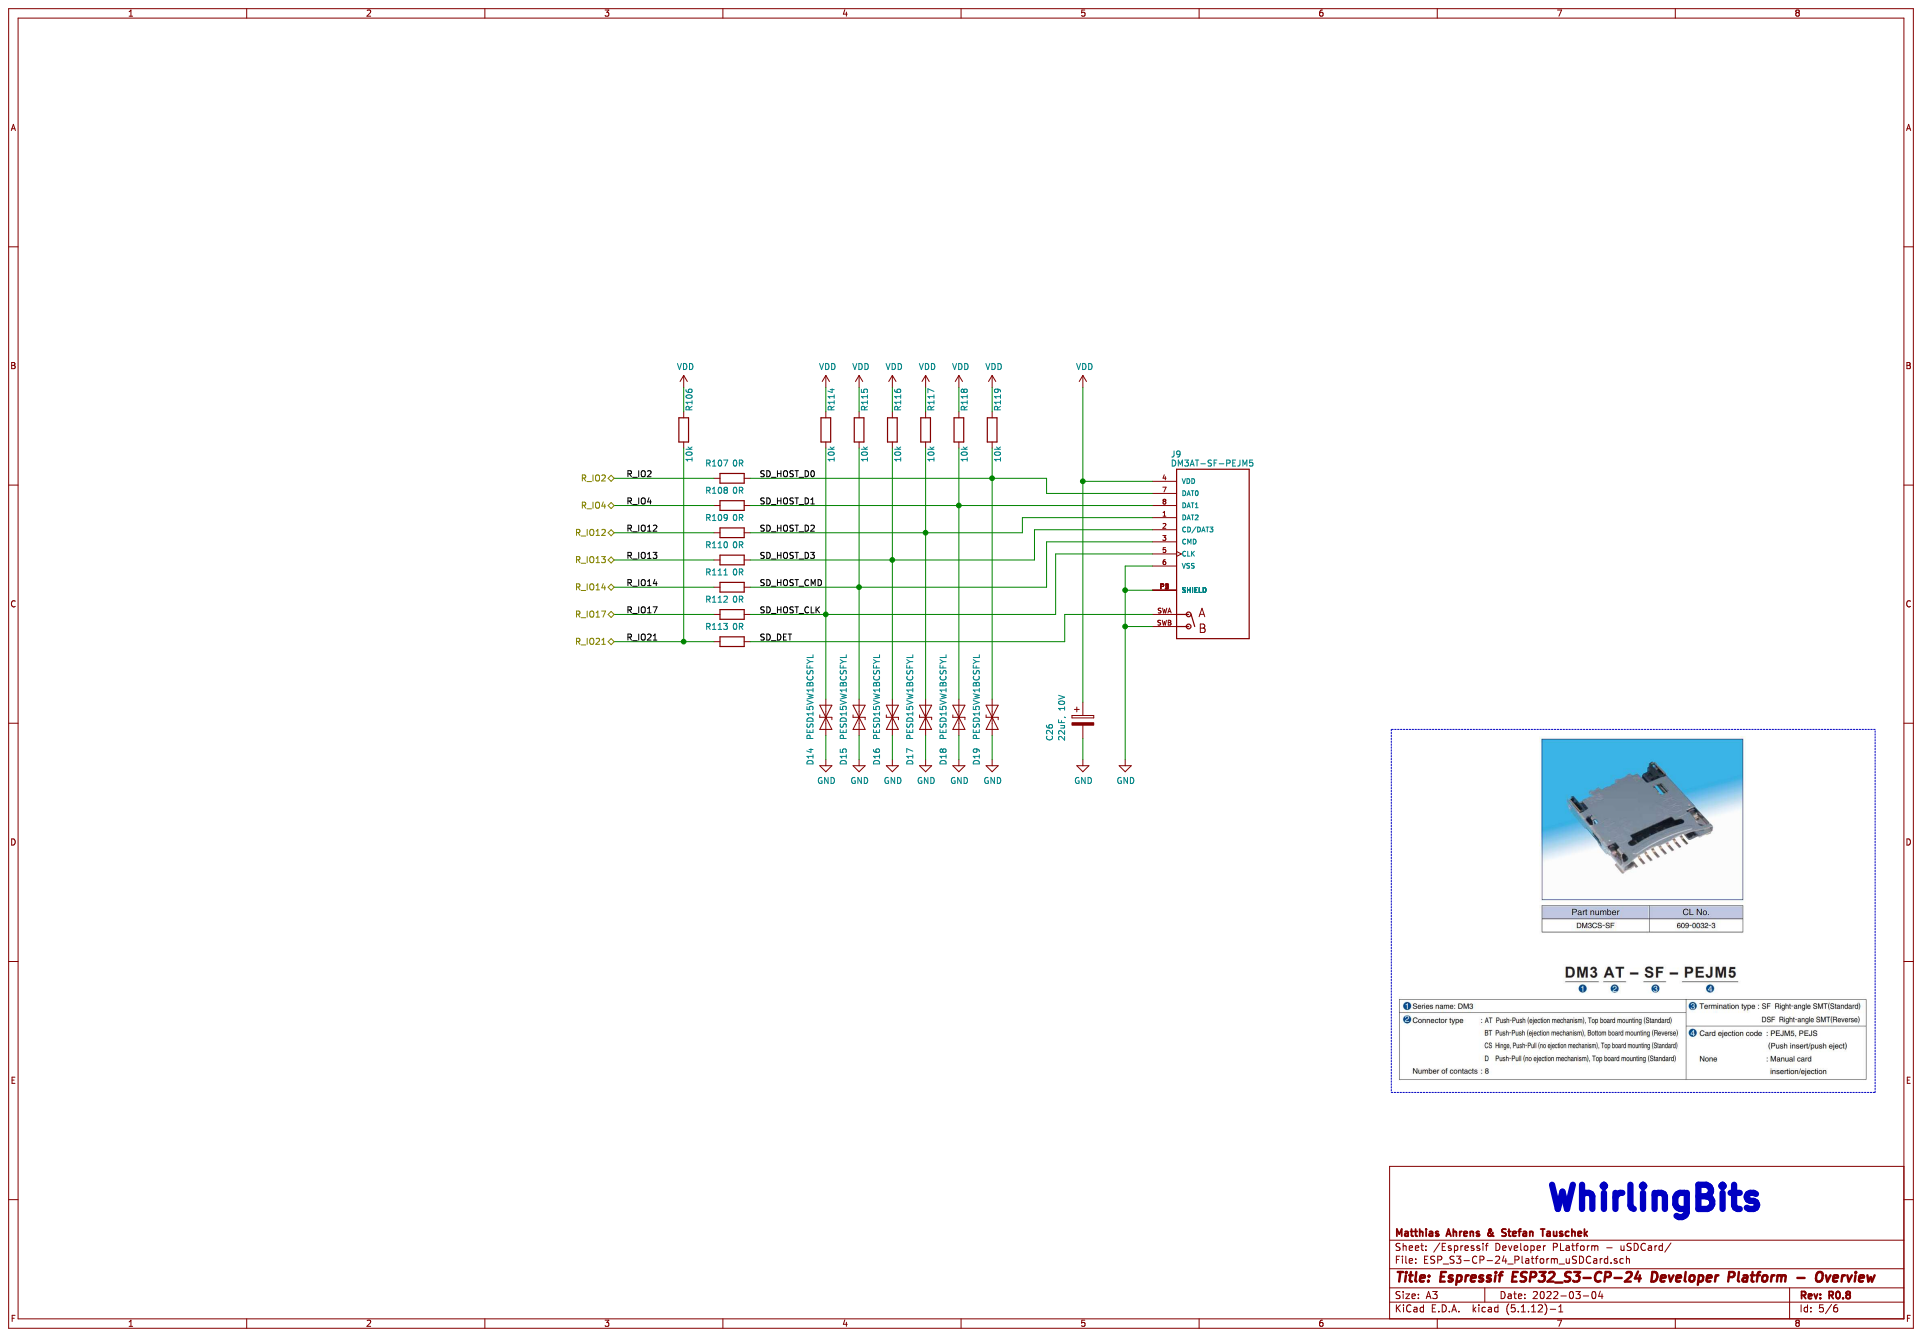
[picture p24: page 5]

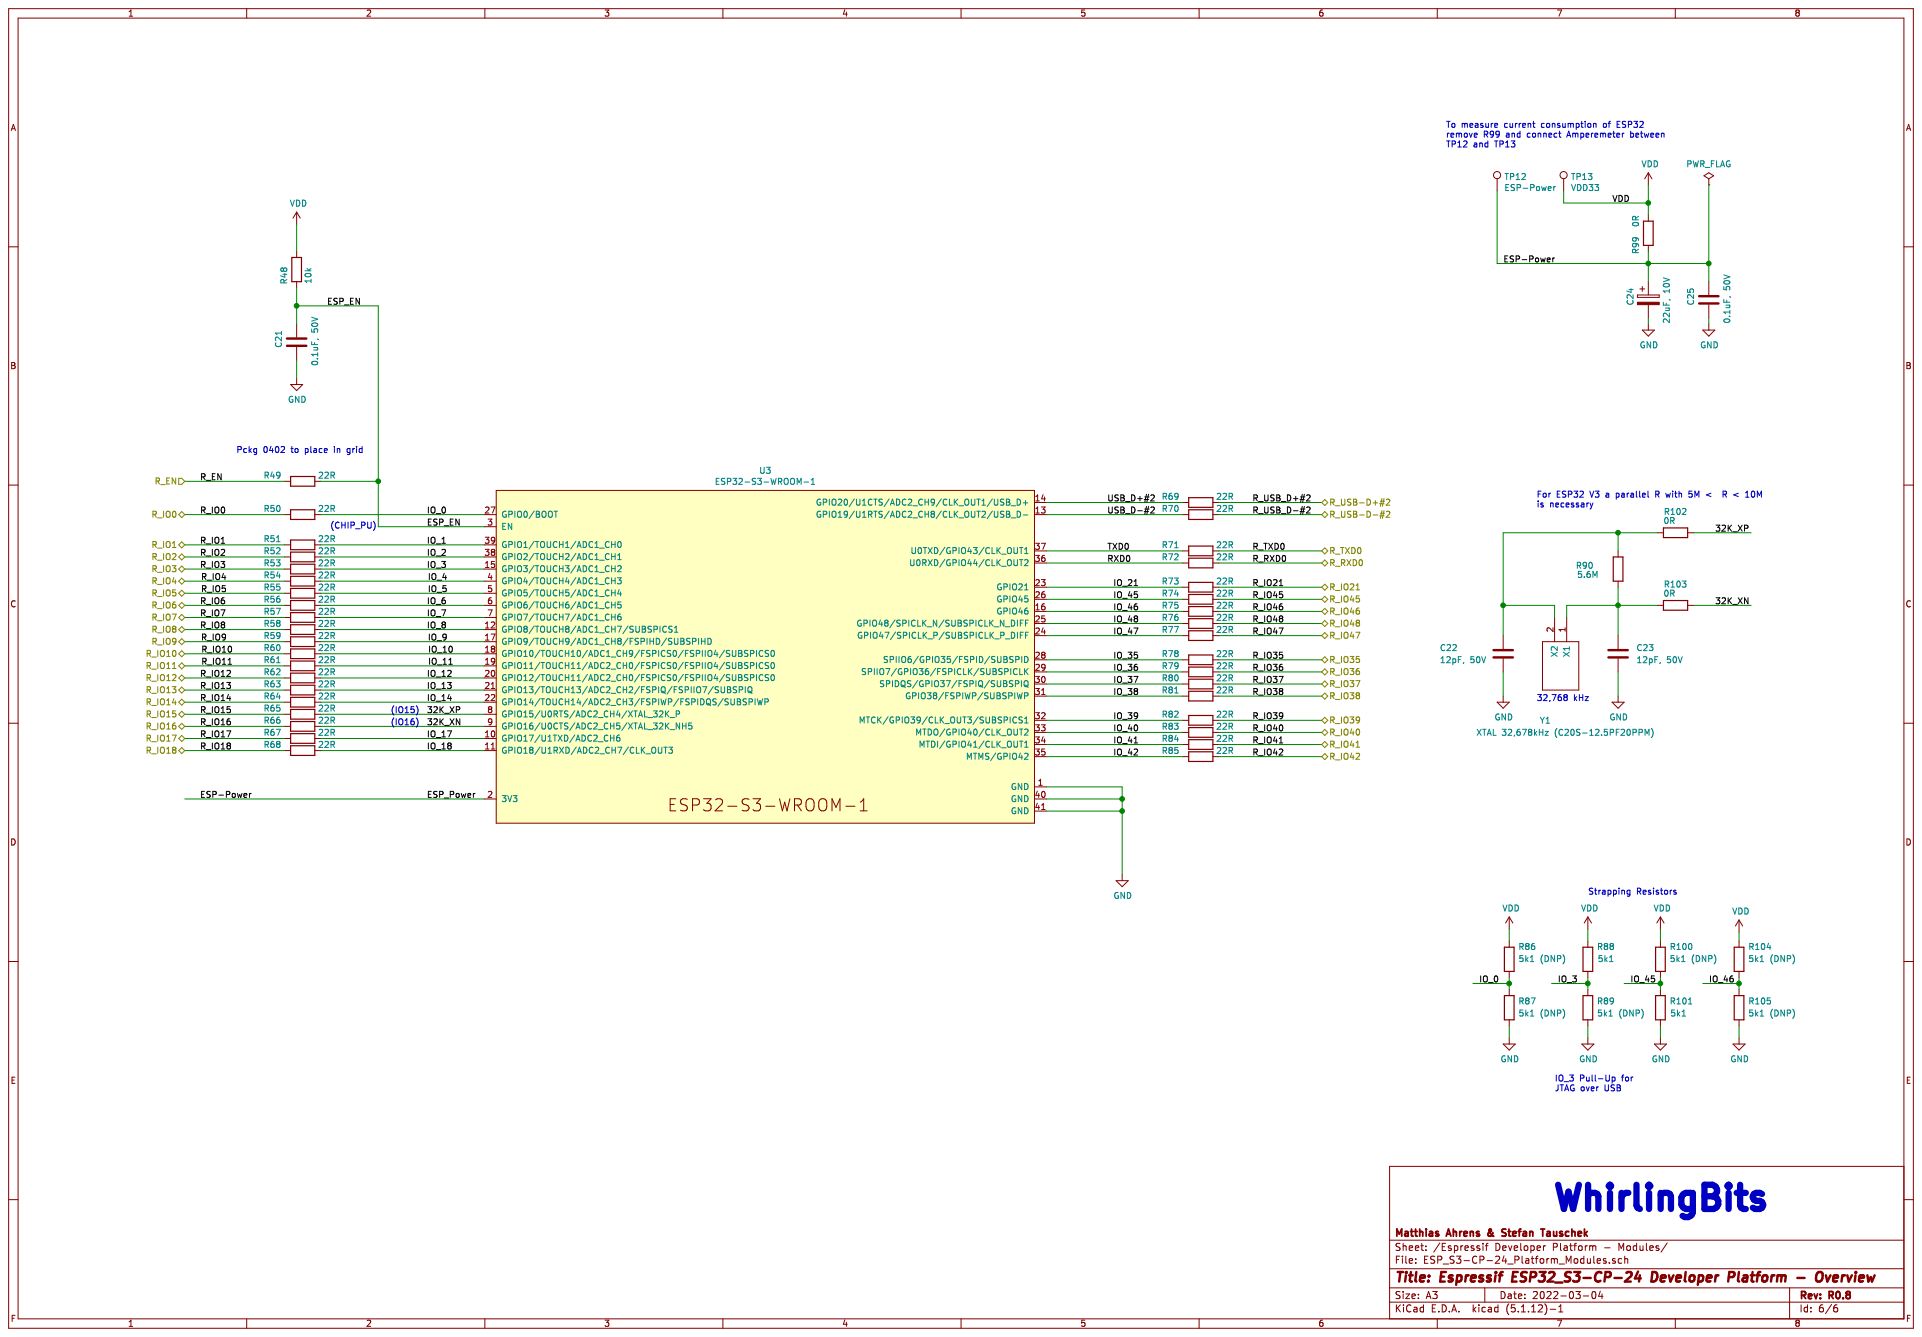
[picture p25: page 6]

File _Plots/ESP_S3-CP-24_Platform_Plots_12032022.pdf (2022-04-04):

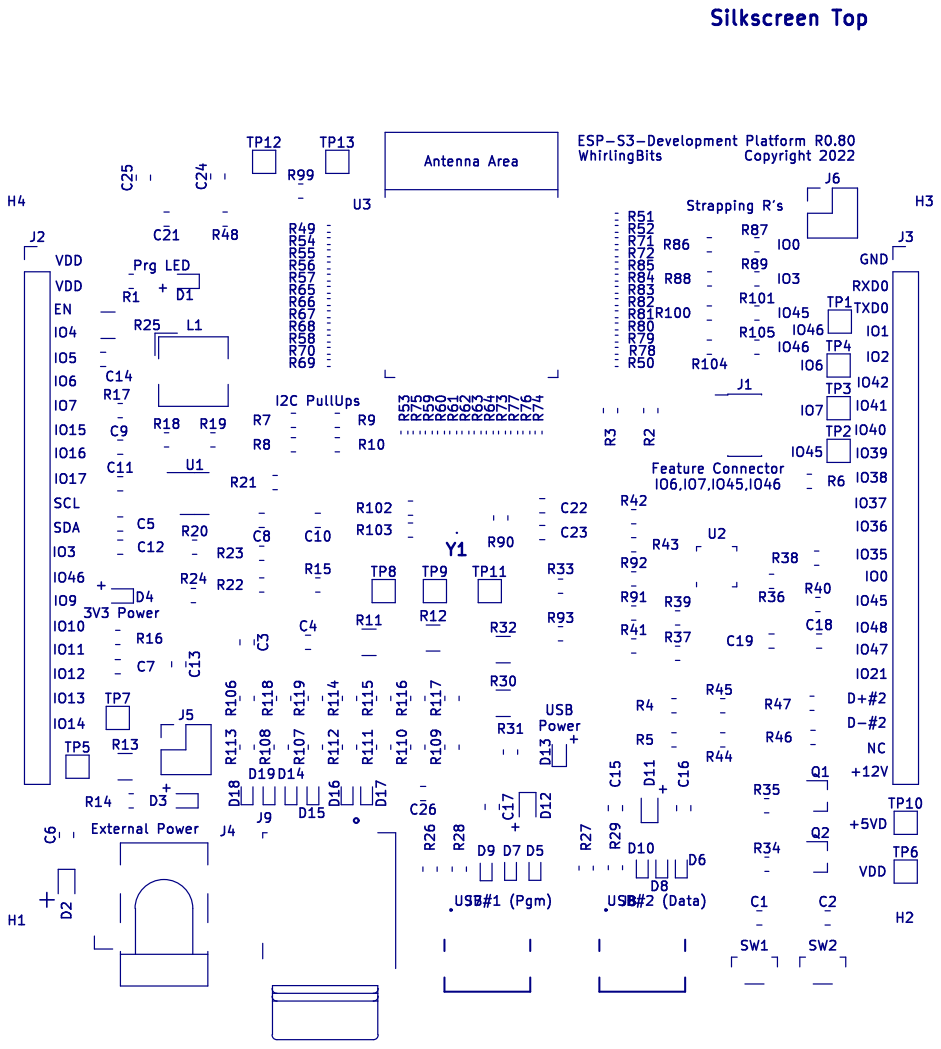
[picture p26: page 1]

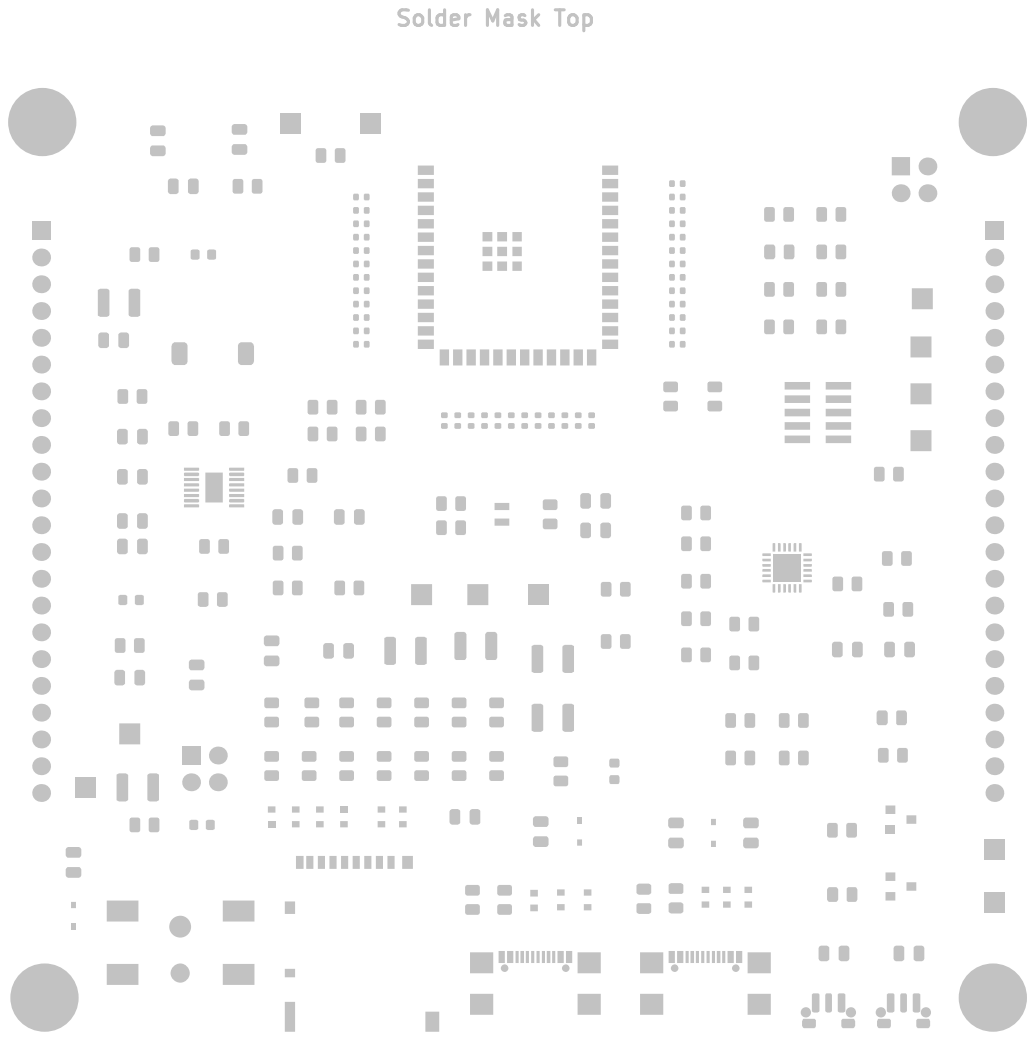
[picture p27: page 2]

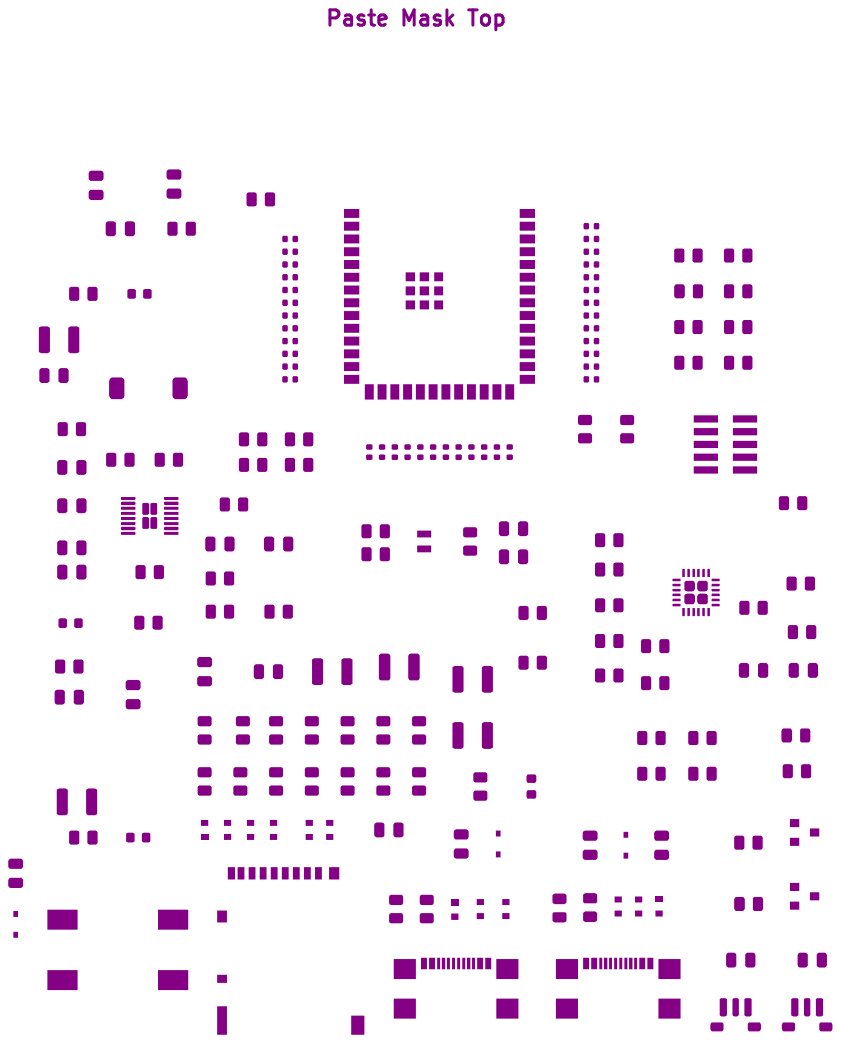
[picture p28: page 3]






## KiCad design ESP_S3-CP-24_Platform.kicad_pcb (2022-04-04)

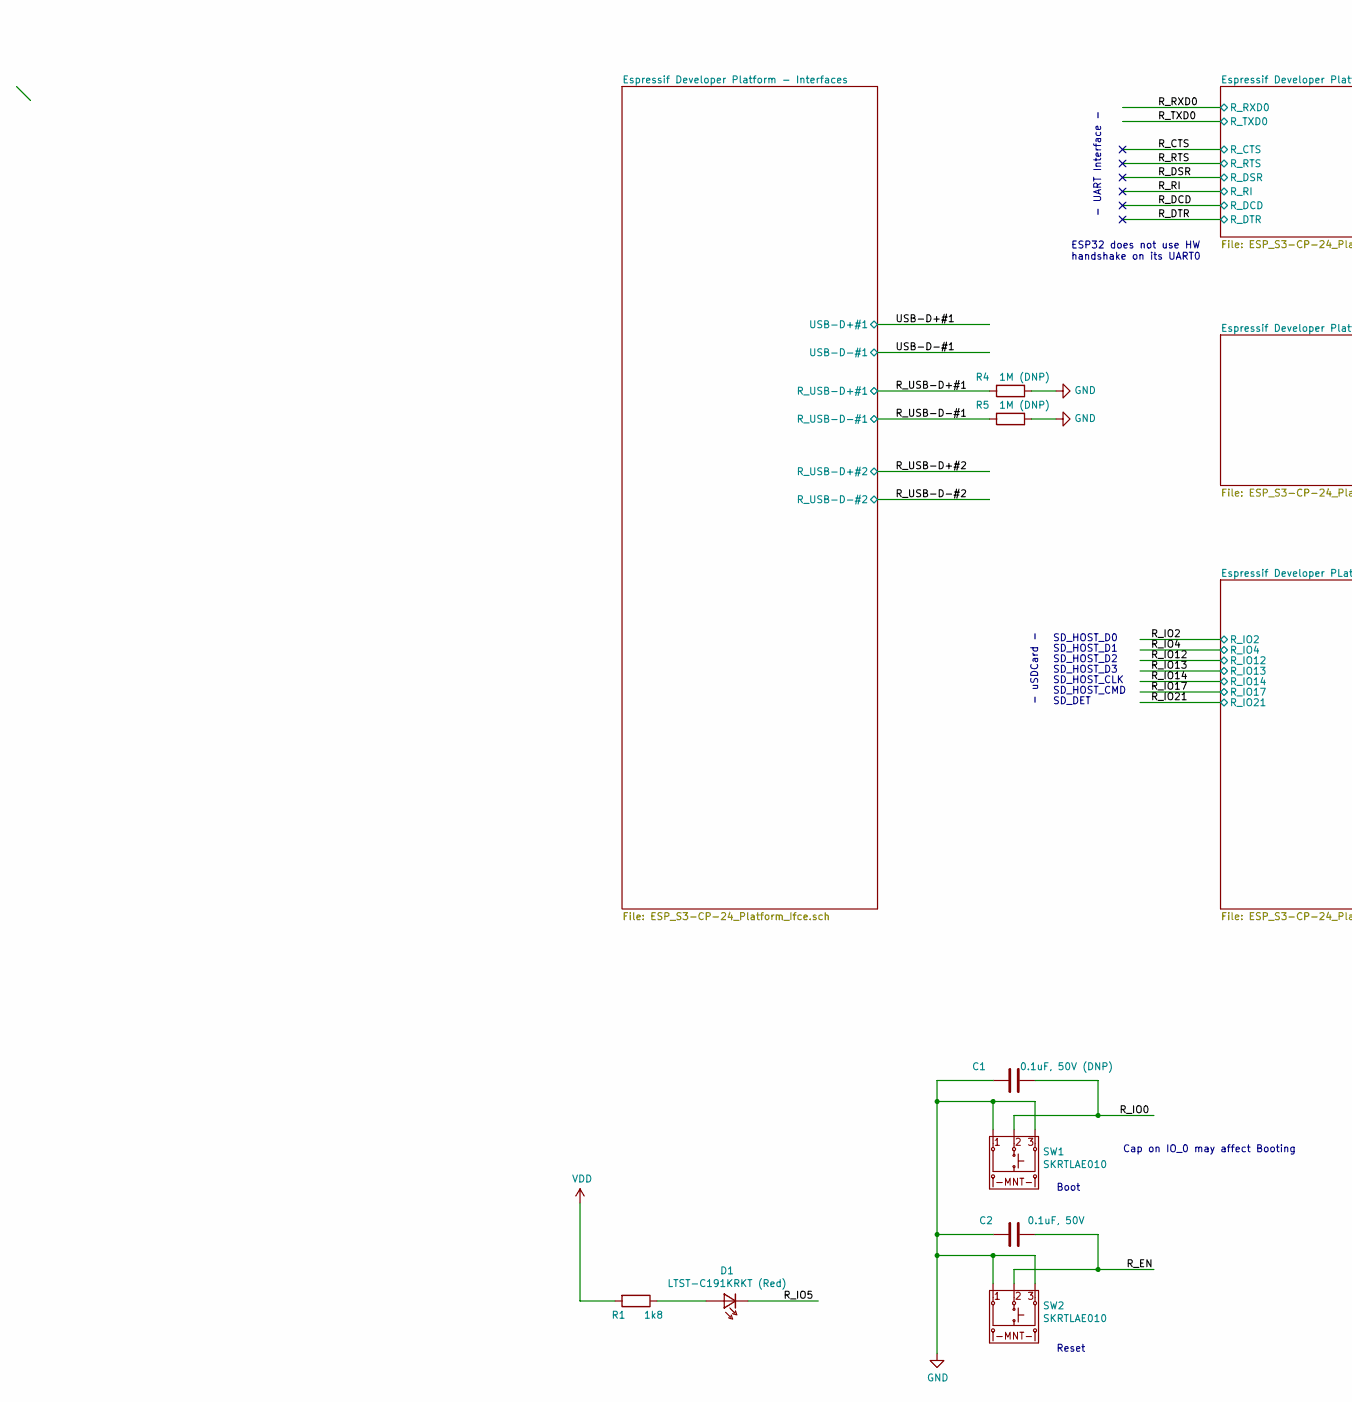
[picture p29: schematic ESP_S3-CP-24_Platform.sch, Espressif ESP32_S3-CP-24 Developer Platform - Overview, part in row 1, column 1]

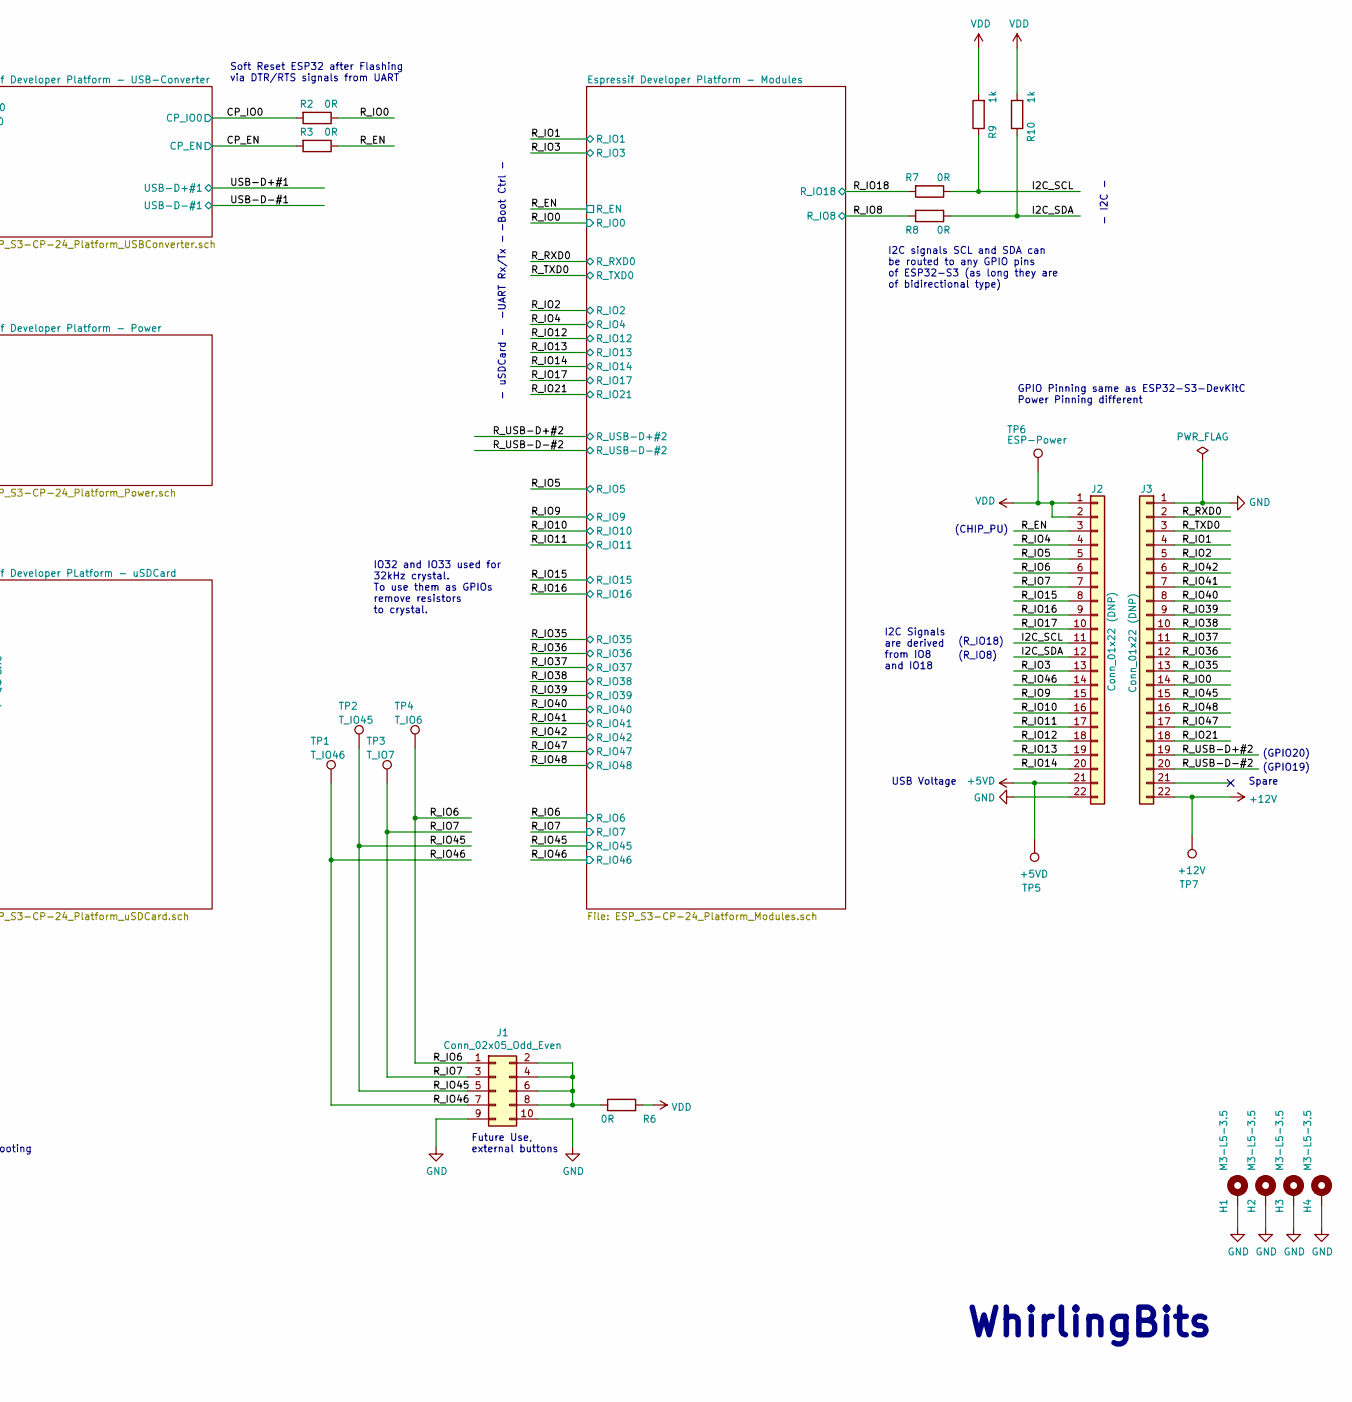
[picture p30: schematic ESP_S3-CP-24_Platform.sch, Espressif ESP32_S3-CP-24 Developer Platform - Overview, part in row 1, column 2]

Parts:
C1: 0.1uF, 50V (DNP); C_0805_2012Metric; LCSC C161260
C2: 0.1uF, 50V; C_0805_2012Metric; LCSC C161260
D1: LTST-C191KRKT (Red); LED_0603_1608Metric; LCSC C125099
H1, H2, H3, H4: M3-L5-3.5; MountingHole_3.2mm_M3_Pad_Via
J1: Conn_02x05_Odd_Even; PinHeader_2x05_P1.27mm_Vertical_SMD; LCSC C150517
J2, J3: Conn_01x22 (DNP); PinHeader_1x22_P2.54mm_Vertical; LCSC C725954
R1: 1k8; R_0805_2012Metric; LCSC C137465
R2, R3, R6: 0R; R_0805_2012Metric
R4, R5: 1M (DNP); R_0805_2012Metric
R7, R8: 0R; R_0805_2012Metric; LCSC C100045
R9, R10: 1k; R_0805_2012Metric; LCSC C95781
SW1, SW2: SKRTLAE010; SW_Push_1P1T-MP_NO_Horizontal_Alps_SKRTLAE010; LCSC C110293
TP1: T_IO46; TestPoint_Pad_2.0x2.0mm
TP2: T_IO45; TestPoint_Pad_2.0x2.0mm
TP3: T_IO7; TestPoint_Pad_2.0x2.0mm
TP4: T_IO6; TestPoint_Pad_2.0x2.0mm
TP5: +5VD; TestPoint_Pad_2.0x2.0mm
TP6: ESP-Power; TestPoint_Pad_2.0x2.0mm
TP7: +12V; TestPoint_Pad_2.0x2.0mm

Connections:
+5VD: J2.21, TP5.1; also elsewhere on the board
+12V: J3.22, TP7.1; also elsewhere on the board
/CP_EN: R3.2; also elsewhere on the board
/CP_IO0: R2.2; also elsewhere on the board
/I2C_SCL: J2.11, R7.1, R9.1
/I2C_SDA: J2.12, R8.1, R10.1
/R_EN: C2.1, J2.3, R3.1, SW2.2; also elsewhere on the board
/R_IO0: C1.1, J3.14, R2.1, SW1.2; also elsewhere on the board
/R_IO1: J3.4; also elsewhere on the board
/R_IO2: J3.5; also elsewhere on the board
/R_IO3: J2.13; also elsewhere on the board
/R_IO4: J2.4; also elsewhere on the board
/R_IO5: D1.1, J2.5; also elsewhere on the board
/R_IO6: J1.1, J2.6, TP4.1; also elsewhere on the board
/R_IO7: J1.3, J2.7, TP3.1; also elsewhere on the board
/R_IO8: R8.2; also elsewhere on the board
/R_IO9: J2.15; also elsewhere on the board
/R_IO10: J2.16; also elsewhere on the board
/R_IO11: J2.17; also elsewhere on the board
/R_IO12: J2.18; also elsewhere on the board
/R_IO13: J2.19; also elsewhere on the board
/R_IO14: J2.20; also elsewhere on the board
/R_IO15: J2.8; also elsewhere on the board
/R_IO16: J2.9; also elsewhere on the board
/R_IO17: J2.10; also elsewhere on the board
/R_IO18: R7.2; also elsewhere on the board
/R_IO21: J3.18; also elsewhere on the board
/R_IO35: J3.13; also elsewhere on the board
/R_IO36: J3.12; also elsewhere on the board
/R_IO37: J3.11; also elsewhere on the board
/R_IO38: J3.10; also elsewhere on the board
/R_IO39: J3.9; also elsewhere on the board
/R_IO40: J3.8; also elsewhere on the board
/R_IO41: J3.7; also elsewhere on the board
/R_IO42: J3.6; also elsewhere on the board
/R_IO45: J1.5, J3.15, TP2.1; also elsewhere on the board
/R_IO46: J1.7, J2.14, TP1.1; also elsewhere on the board
/R_IO47: J3.17; also elsewhere on the board
/R_IO48: J3.16; also elsewhere on the board
/R_RXD0: J3.2; also elsewhere on the board
/R_TXD0: J3.3; also elsewhere on the board
/R_USB-D+#1: R4.2; also elsewhere on the board
/R_USB-D+#2: J3.19; also elsewhere on the board
/R_USB-D-#1: R5.2; also elsewhere on the board
/R_USB-D-#2: J3.20; also elsewhere on the board
GND: C1.2, C2.2, H1.1, H2.1, H3.1, H4.1, J1.9, J1.10, J2.22, J3.1, R4.1, R5.1, SW1.1, SW1.3, SW2.1, SW2.3; also elsewhere on the board
unnamed: D1.2, R1.1
unnamed: J1.2, J1.4, J1.6, J1.8, R6.1
VDD: J2.1, J2.2, R1.2, R6.2, R9.2, R10.2, TP6.1; also elsewhere on the board

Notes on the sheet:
I2C signals SCL and SDA can be routed to any GPIO pins of ESP32-S3 (as long they are of bidirectional type)
- I2C -
-Boot Ctrl -
- UART Interface -
ESP32 does not use HW handshake on its UART0
-UART Rx/Tx -
Reset
Boot
Cap on IO_0 may affect Booting
Future Use, external buttons
- uSDCard -
Soft Reset ESP32 after Flashing via DTR/RTS signals from UART
USB Voltage
I2C Signals are derived from IO8 and IO18
IO32 and IO33 used for 32kHz crystal. To use them as GPIOs remove resistors to crystal.
SD_HOST_D0
SD_HOST_D1
SD_HOST_D2
SD_HOST_D3
SD_HOST_CLK
SD_HOST_CMD
SD_DET
(R_IO18)
(R_IO8)
(CHIP_PU)
GPIO Pinning same as ESP32-S3-DevKitC Power Pinning different
Spare
(GPIO20)
(GPIO19)
WhirlingBits

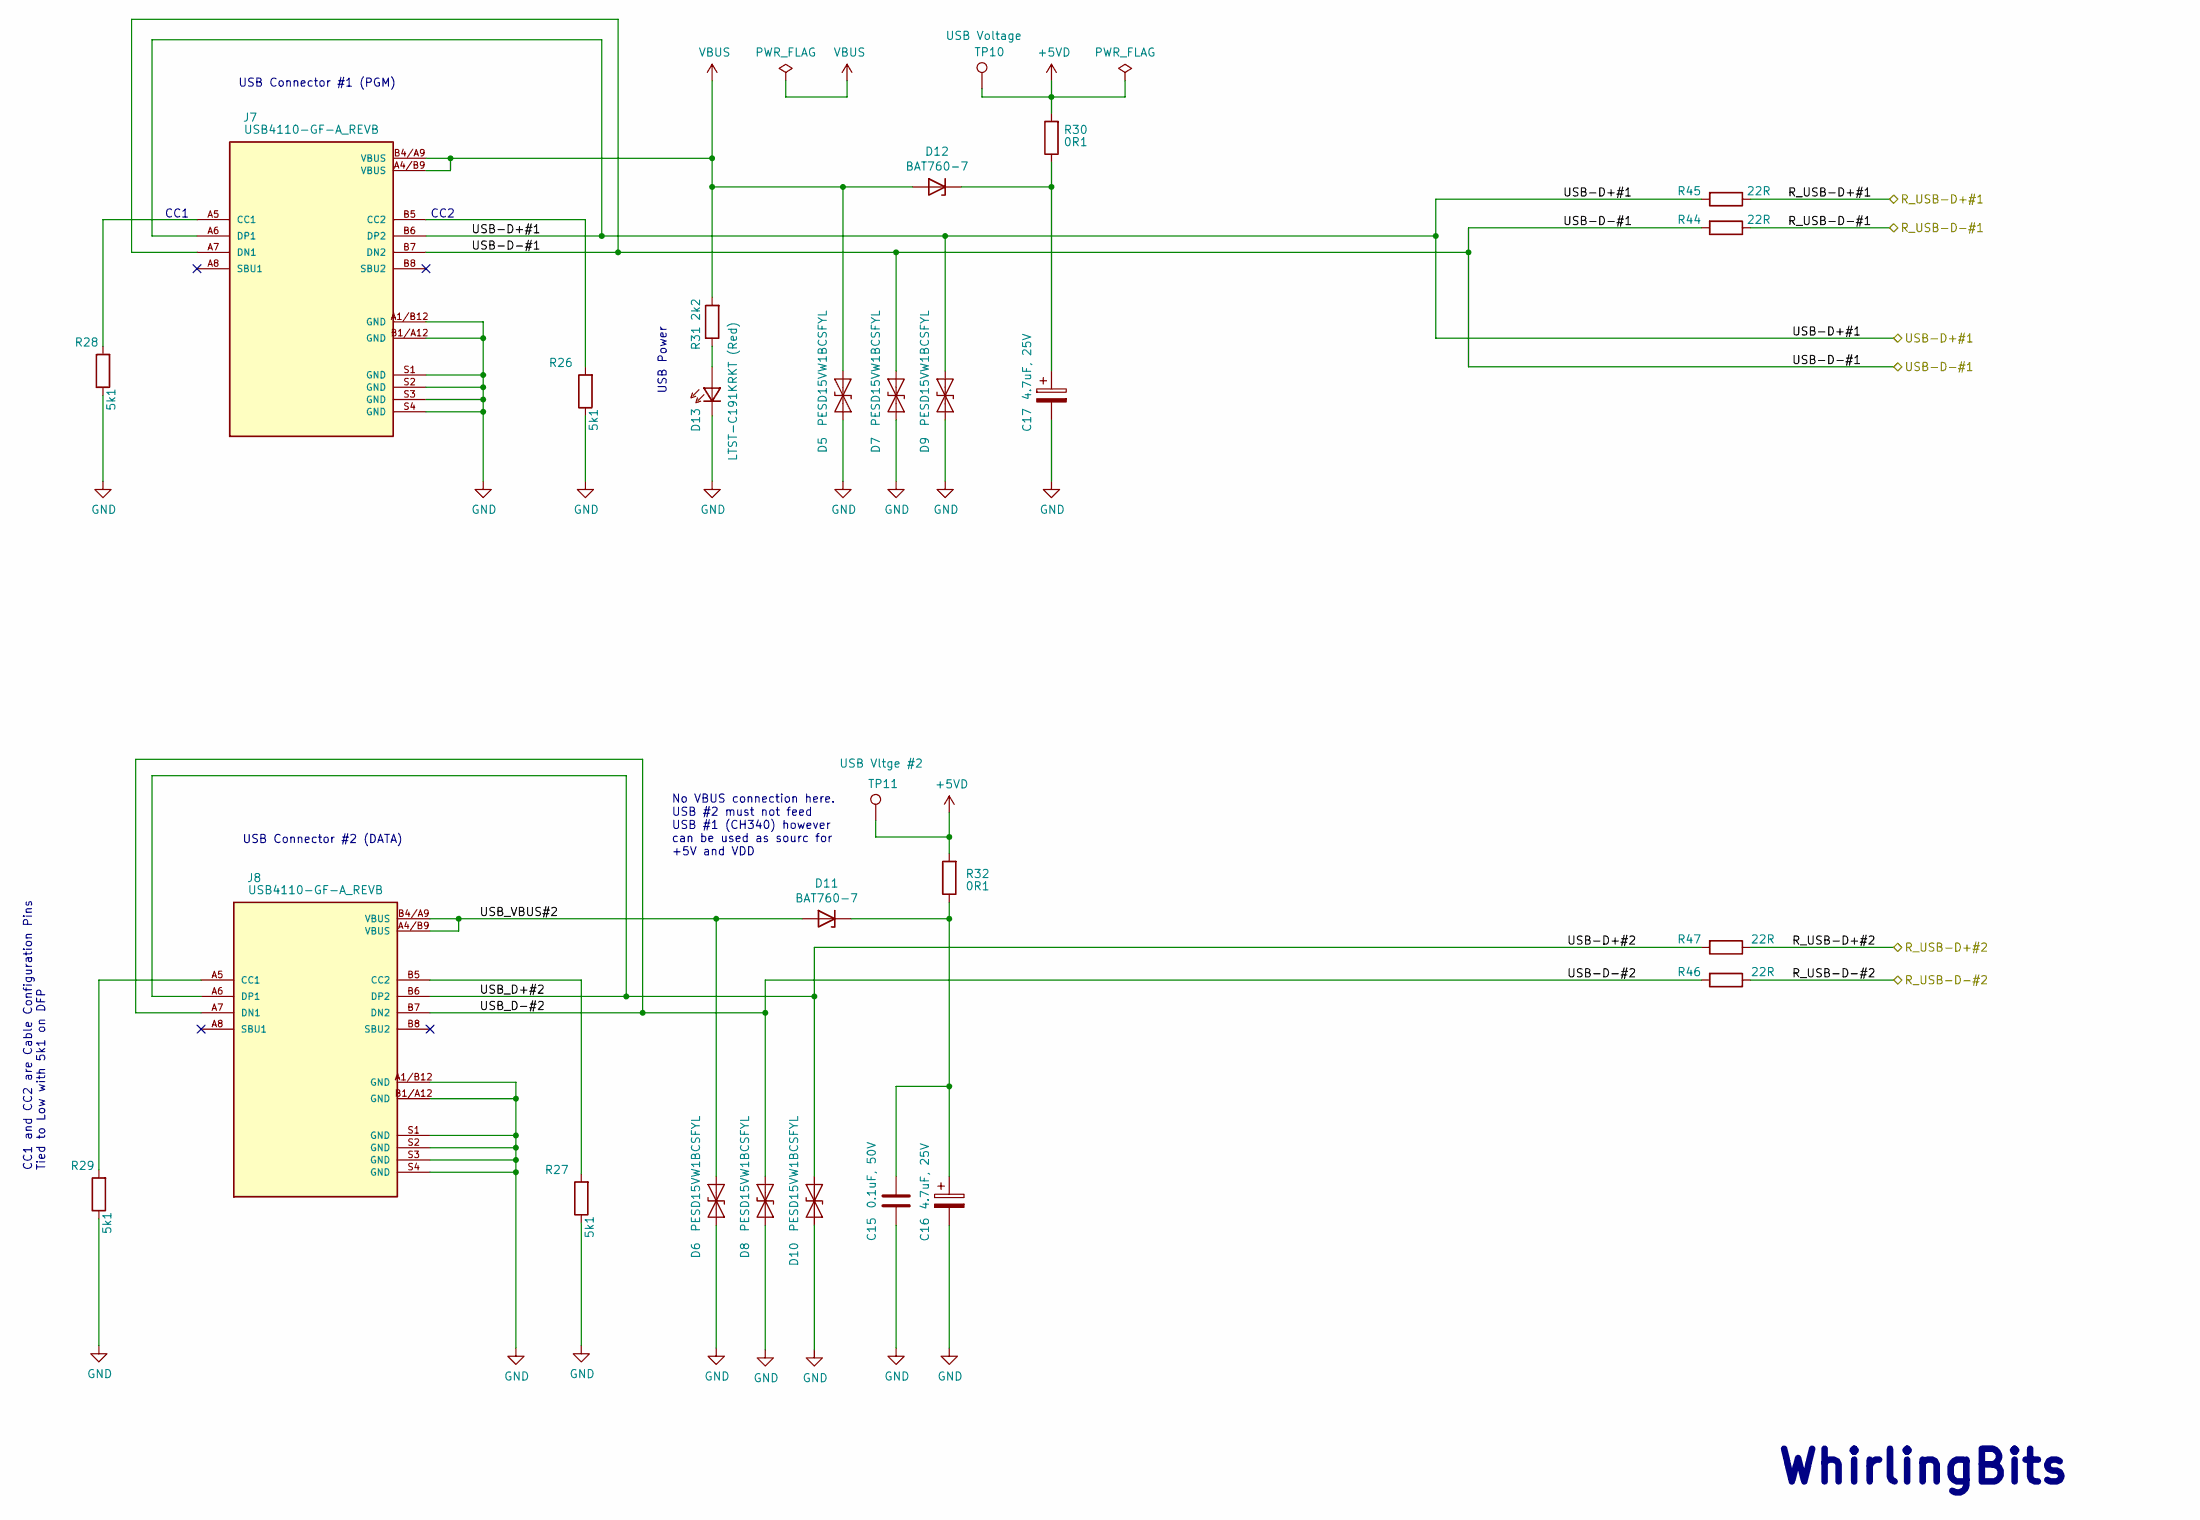
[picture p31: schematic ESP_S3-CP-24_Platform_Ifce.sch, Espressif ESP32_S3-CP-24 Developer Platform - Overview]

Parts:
C15: 0.1uF, 50V; C_0805_2012Metric; LCSC C161260
C16, C17: 4.7uF, 25V; C_0805_2012Metric; LCSC C98192
D5, D6, D7, D8, D9, D10: PESD15VW1BCSFYL; D_SOD-523; Mouser Part Number 771-PESD15VW1BCSFYL; Mouser 771-PESD15VW1BCSFYL
D11, D12: BAT760-7; D_SOD-323; LCSC C116158
D13: LTST-C191KRKT (Red); LED_0603_1608Metric; LCSC C125099
J7, J8: USB4110-GF-A_REVB; GCT_USB4110-GF-A_REVB; PARTREV B; Mouser 640-USB4110-GF-A
R26, R27, R28, R29: 5k1; R_0805_2012Metric; LCSC C204548
R30, R32: 0R1; R_1210_3225Metric; LCSC C473589
R31: 2k2; R_0805_2012Metric; LCSC C441982
R44, R45, R46, R47: 22R; R_0805_2012Metric; LCSC C144531
TP10: USB Voltage; TestPoint_Pad_2.0x2.0mm
TP11: USB Vltge #2; TestPoint_Pad_2.0x2.0mm

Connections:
+5VD: R30.2, R32.2, TP10.1, TP11.1; also elsewhere on the board
/Espressif Developer Platform - Interfaces/USB-D+#2: D10.1 (A1), J8.A6 (DP1), J8.B6 (DP2), R47.2
/Espressif Developer Platform - Interfaces/USB-D-#2: D8.1 (A1), J8.A7 (DN1), J8.B7 (DN2), R46.2
/Espressif Developer Platform - Interfaces/USB_VBUS#2: D6.1 (A1), D11.2 (A), J8.A4/B9 (VBUS), J8.B4/A9 (VBUS)
/R_USB-D+#1: R45.1; also elsewhere on the board
/R_USB-D+#2: R47.1; also elsewhere on the board
/R_USB-D-#1: R44.1; also elsewhere on the board
/R_USB-D-#2: R46.1; also elsewhere on the board
/USB-D+#1: D9.1 (A1), J7.A6 (DP1), J7.B6 (DP2), R45.2; also elsewhere on the board
/USB-D-#1: D7.1 (A1), J7.A7 (DN1), J7.B7 (DN2), R44.2; also elsewhere on the board
GND: C15.2, C16.2, C17.2, D5.2 (A2), D6.2 (A2), D7.2 (A2), D8.2 (A2), D9.2 (A2), D10.2 (A2), D13.1, J7.A1/B12 (GND), J7.B1/A12 (GND), J7.S1 (GND), J7.S2 (GND), J7.S3 (GND), J7.S4 (GND), J8.A1/B12 (GND), J8.B1/A12 (GND), J8.S1 (GND), J8.S2 (GND), J8.S3 (GND), J8.S4 (GND), R26.1, R27.1, R28.1, R29.1; also elsewhere on the board
unnamed: C15.1, C16.1, D11.1 (K), R32.1
unnamed: C17.1, D12.1 (K), R30.1
unnamed: D13.2, R31.1
unnamed: J7.A5 (CC1), R28.2
unnamed: J7.B5 (CC2), R26.2
unnamed: J8.A5 (CC1), R29.2
unnamed: J8.B5 (CC2), R27.2
VBUS: D5.1 (A1), D12.2 (A), J7.A4/B9 (VBUS), J7.B4/A9 (VBUS), R31.2; also elsewhere on the board

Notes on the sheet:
USB Connector #1 (PGM)
USB Power
USB Connector #2 (DATA)
No VBUS connection here. USB #2 must not feed USB #1 (CH340) however can be used as sourc for +5V and VDD
CC1 and CC2 are Cable Configuration Pins Tied to Low with 5k1 on DFP
CC1
CC2
WhirlingBits

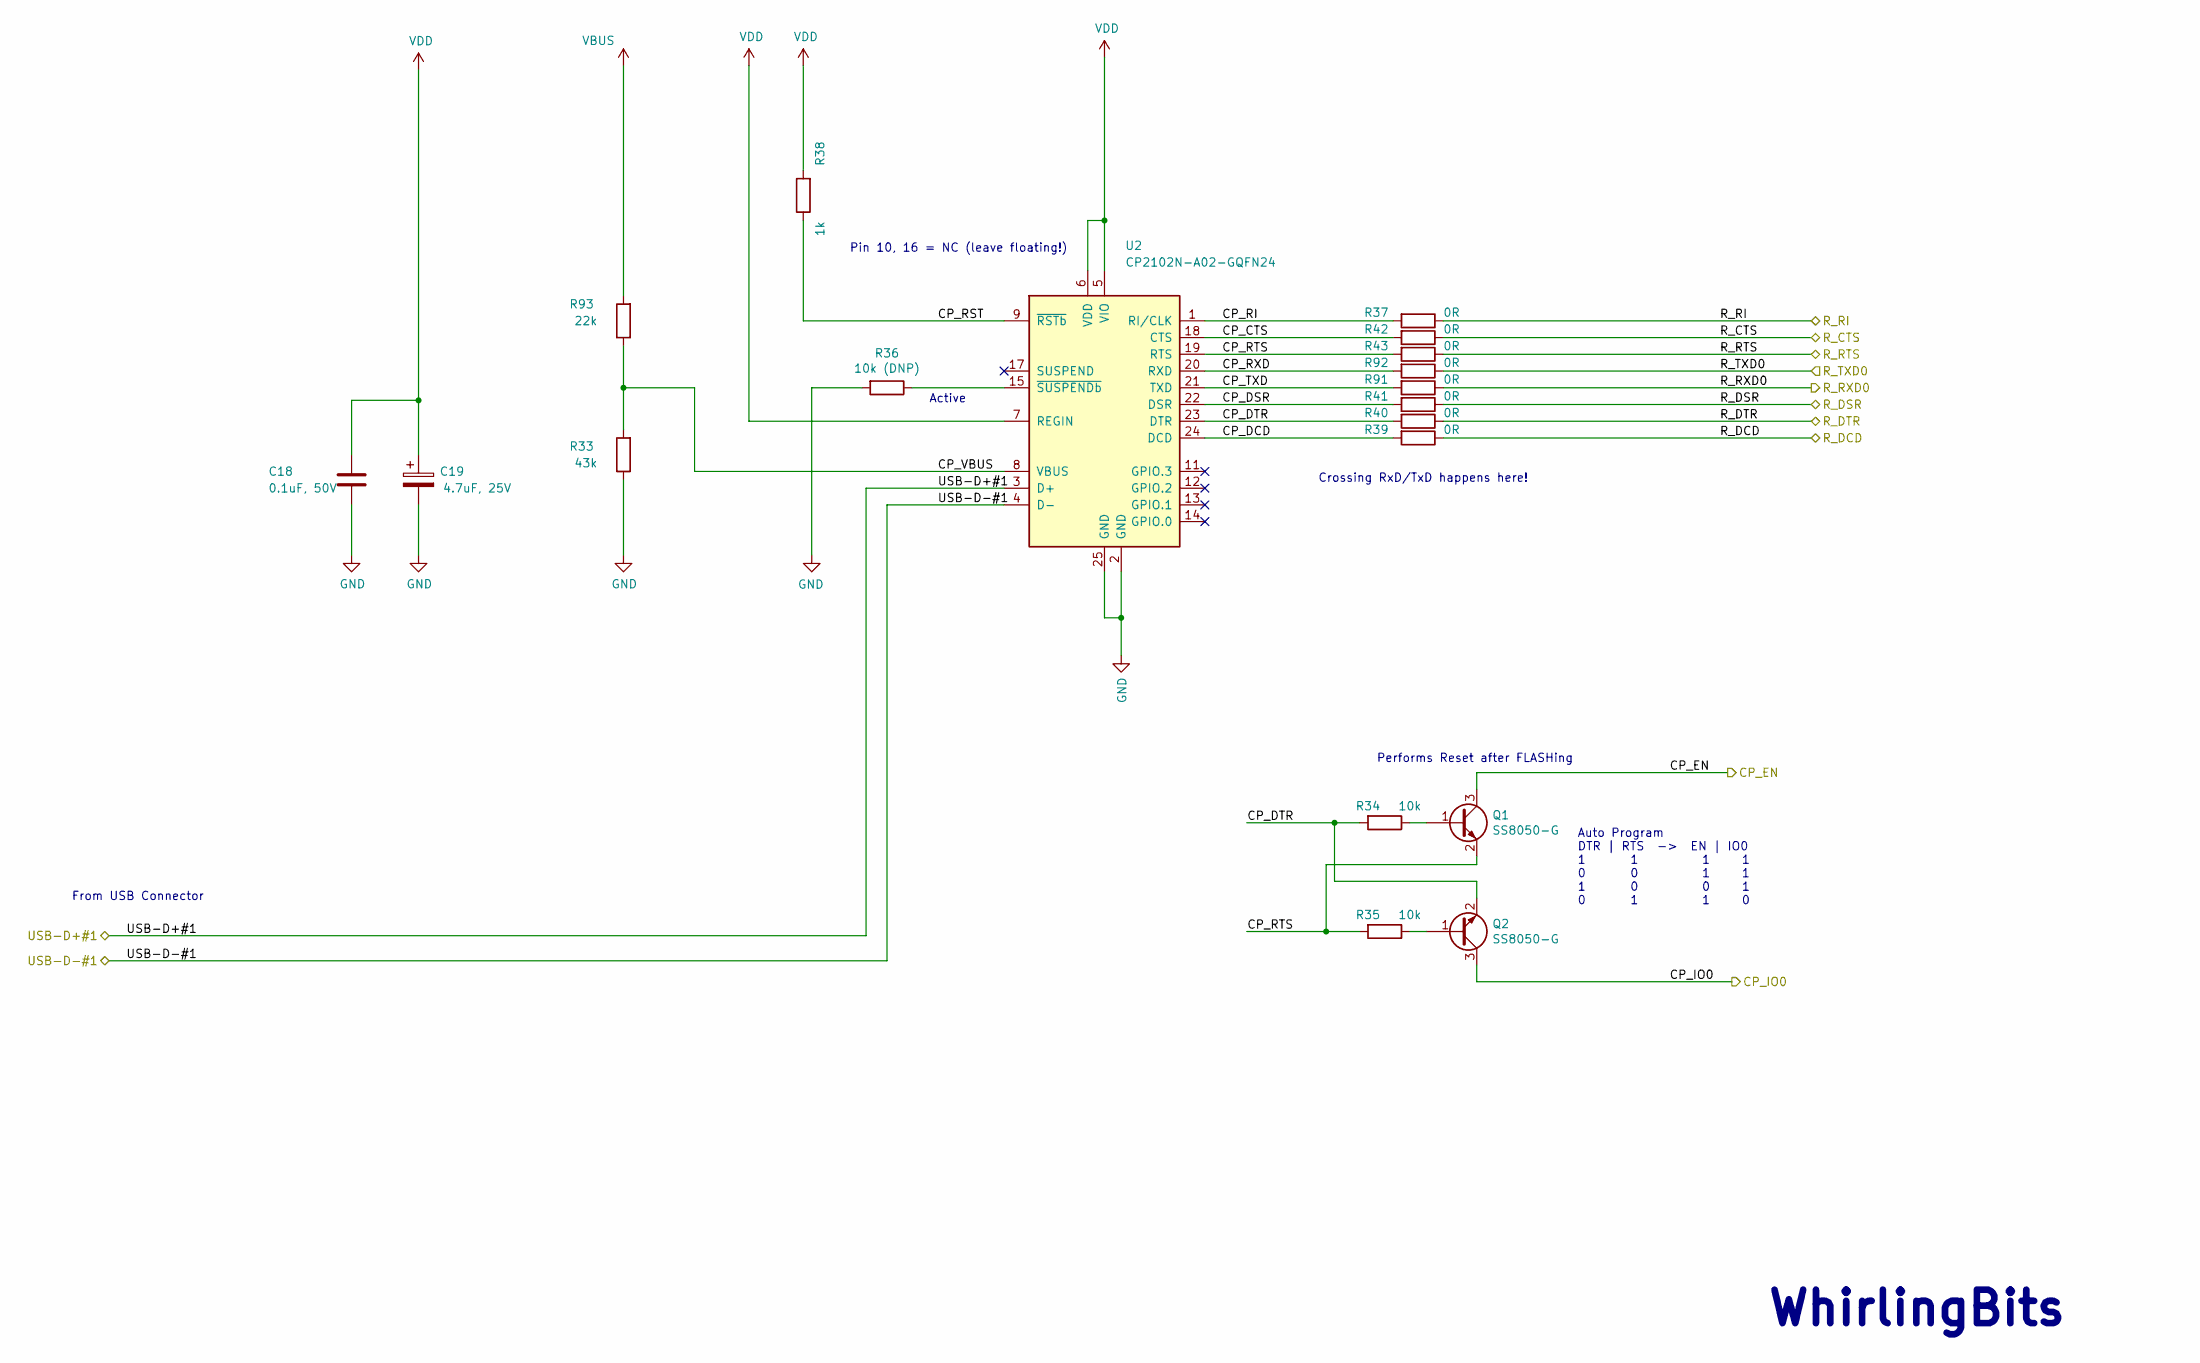
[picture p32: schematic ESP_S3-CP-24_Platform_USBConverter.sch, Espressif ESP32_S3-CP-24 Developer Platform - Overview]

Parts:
C18: 0.1uF, 50V; C_0805_2012Metric; LCSC C161260
C19: 4.7uF, 25V; C_0805_2012Metric; LCSC C98192
Q1, Q2: SS8050-G; SOT-23; LCSC C164885
R33: 43k; R_0805_2012Metric; LCSC C104355
R34, R35: 10k; R_0805_2012Metric; LCSC C169253
R36: 10k (DNP); R_0805_2012Metric
R37, R39, R40, R41, R42, R43, R91, R92: 0R; R_0805_2012Metric
R38: 1k; R_0805_2012Metric
R93: 22k; R_0805_2012Metric; LCSC C104113
U2: CP2102N-A02-GQFN24; QFN-24-1EP_4x4mm_P0.5mm_EP2.6x2.6mm; LCSC C80225

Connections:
/CP_EN: Q1.3 (C); also elsewhere on the board
/CP_IO0: Q2.3 (C); also elsewhere on the board
/Espressif Developer Platform - USB-Converter/CP_CTS: R42.2, U2.18 (CTS)
/Espressif Developer Platform - USB-Converter/CP_DCD: R39.2, U2.24 (DCD)
/Espressif Developer Platform - USB-Converter/CP_DSR: R41.2, U2.22 (DSR)
/Espressif Developer Platform - USB-Converter/CP_DTR: Q2.2 (E), R34.2, R40.2, U2.23 (DTR)
/Espressif Developer Platform - USB-Converter/CP_RI: R37.2, U2.1 (RI/CLK)
/Espressif Developer Platform - USB-Converter/CP_RST: R38.1, U2.9 (~RSTb)
/Espressif Developer Platform - USB-Converter/CP_RTS: Q1.2 (E), R35.2, R43.2, U2.19 (RTS)
/Espressif Developer Platform - USB-Converter/CP_RXD: R92.2, U2.20 (RXD)
/Espressif Developer Platform - USB-Converter/CP_TXD: R91.2, U2.21 (TXD)
/Espressif Developer Platform - USB-Converter/CP_VBUS: R33.2, R93.1, U2.8 (VBUS)
/R_CTS: R42.1
/R_DCD: R39.1
/R_DSR: R41.1
/R_DTR: R40.1
/R_RI: R37.1
/R_RTS: R43.1
/R_RXD0: R91.1; also elsewhere on the board
/R_TXD0: R92.1; also elsewhere on the board
/USB-D+#1: U2.3 (D+); also elsewhere on the board
/USB-D-#1: U2.4 (D-); also elsewhere on the board
GND: C18.2, C19.2, R33.1, R36.2, U2.2 (GND), U2.25 (GND); also elsewhere on the board
unnamed: Q1.1 (B), R34.1
unnamed: Q2.1 (B), R35.1
unnamed: R36.1, U2.15 (~SUSPENDb)
VBUS: R93.2; also elsewhere on the board
VDD: C18.1, C19.1, R38.2, U2.5 (VIO), U2.6 (VDD), U2.7 (REGIN); also elsewhere on the board

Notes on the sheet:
Active
From USB Connector
Crossing RxD/TxD happens here!
Auto Program DTR | RTS -> EN | IO0 1 1 1 1 0 0 1 1 1 0 0 1 0 1 1 0
Performs Reset after FLASHing
Pin 10, 16 = NC (leave floating!)
WhirlingBits

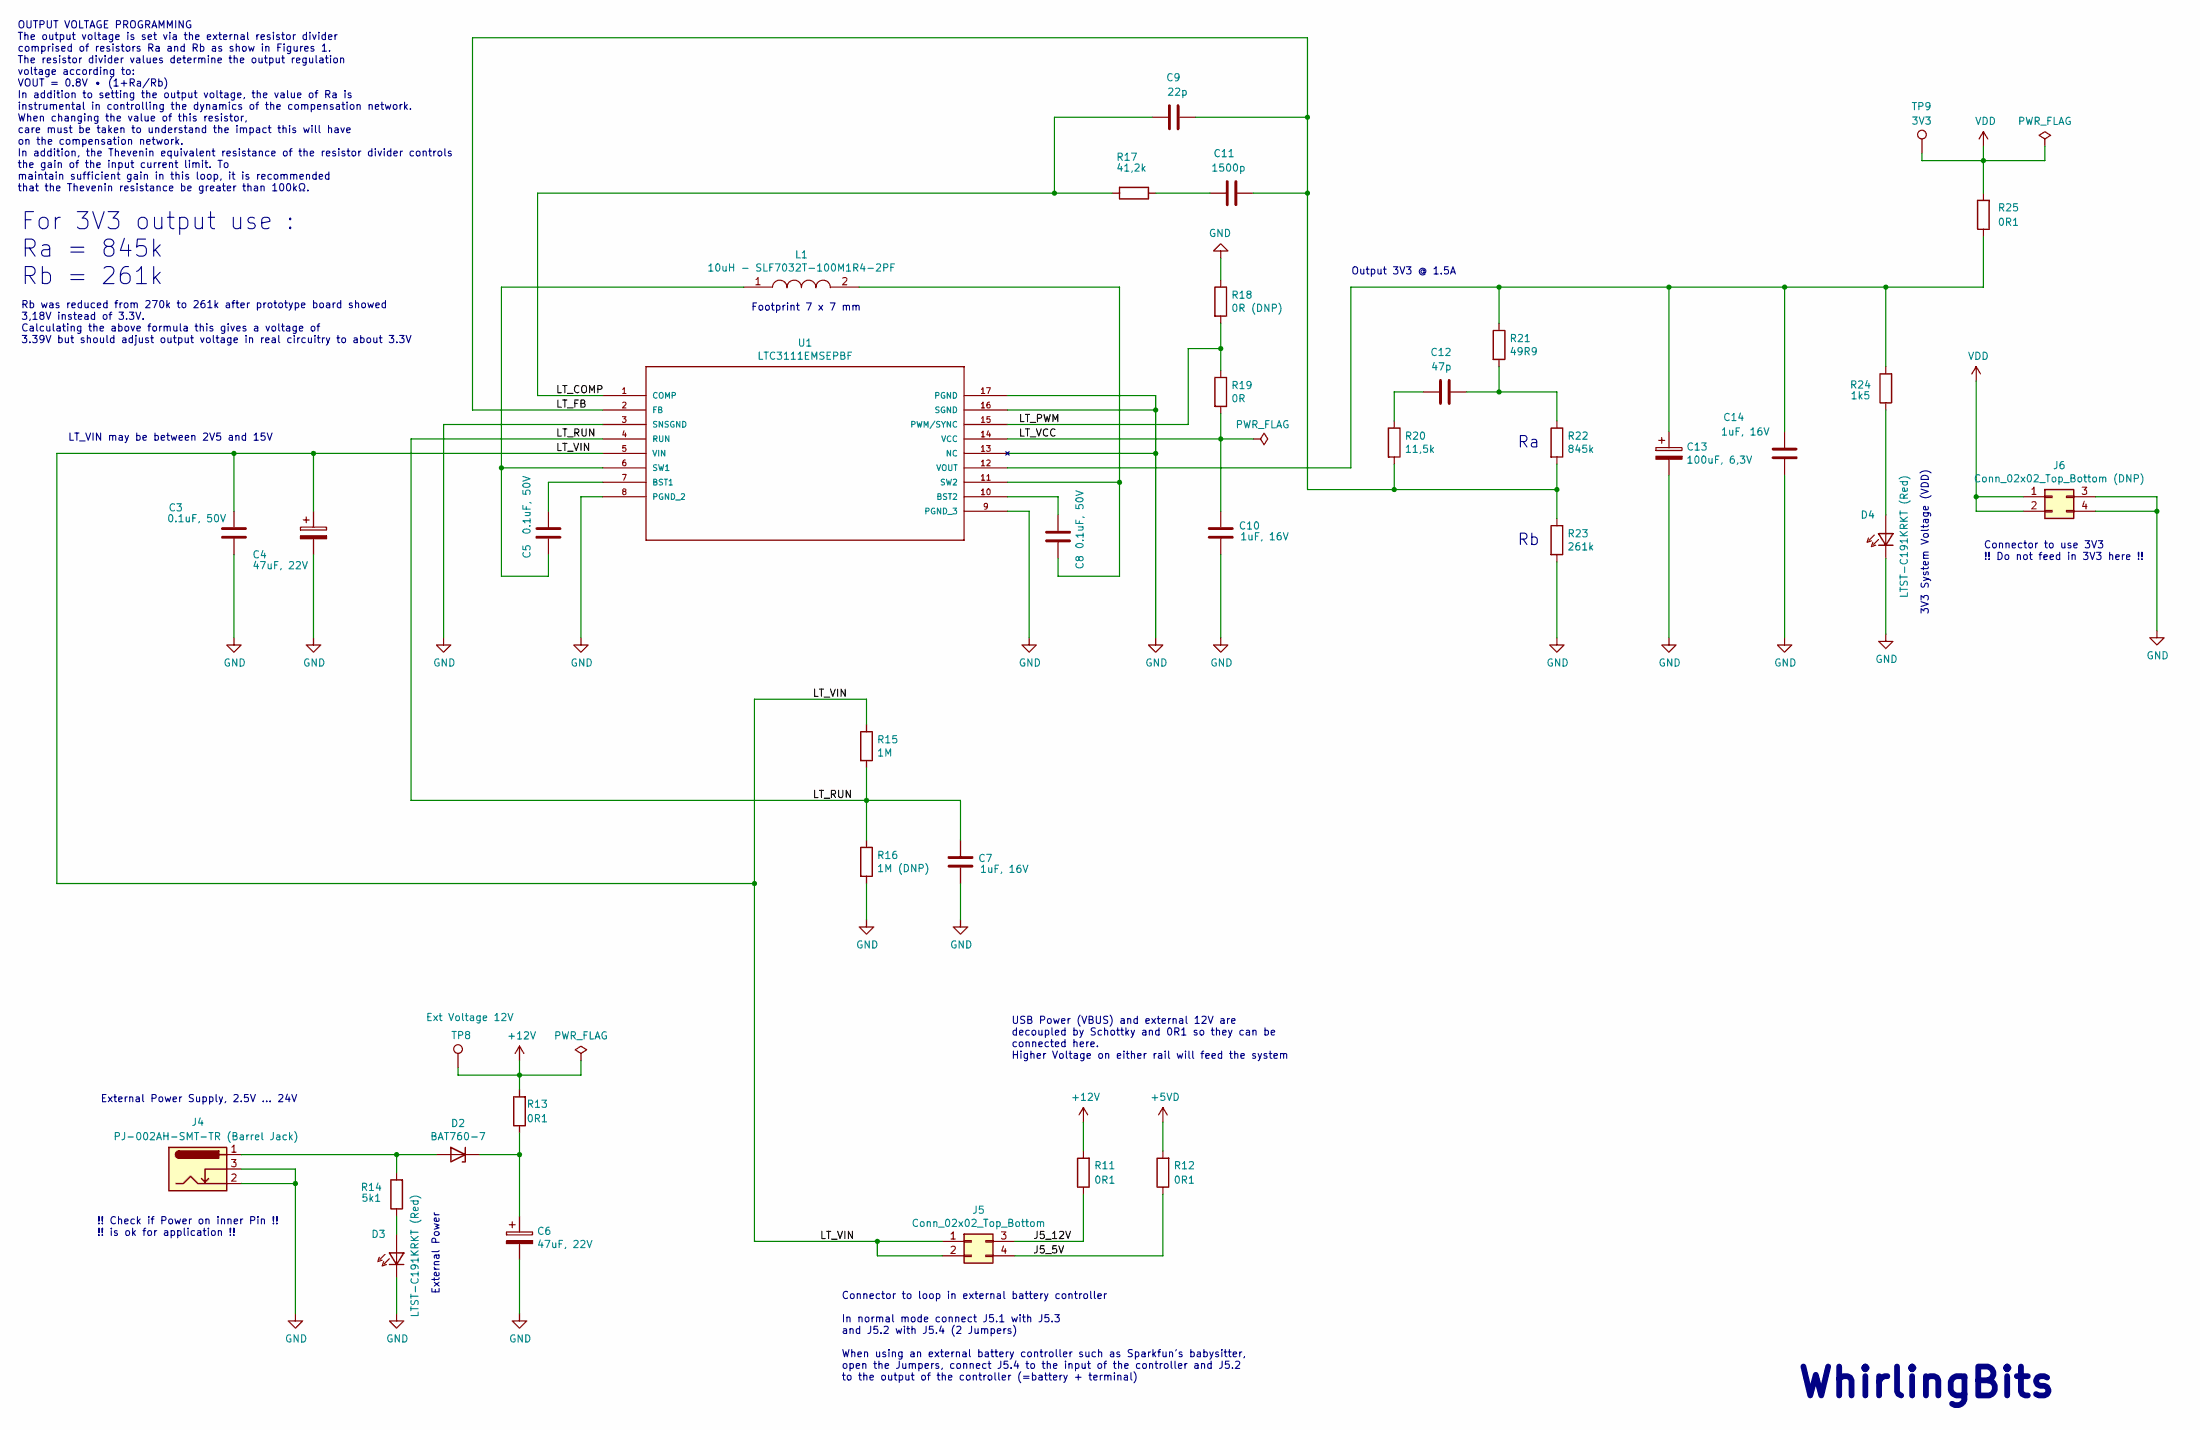
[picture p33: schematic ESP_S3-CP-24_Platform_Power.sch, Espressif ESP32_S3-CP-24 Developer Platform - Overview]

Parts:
C3, C5, C8: 0.1uF, 50V; C_0805_2012Metric; LCSC C161260
C4, C6: 47uF, 22V; C_0805_2012Metric; Mouser Part Number 810-C2012X5R1A476M; LCSC C90142
C7, C10, C14: 1uF, 16V; C_0805_2012Metric; LCSC C16834
C9: 22p; C_0805_2012Metric; LCSC C105623
C11: 1500p; C_0805_2012Metric; LCSC C114765
C12: 47p; C_0805_2012Metric; LCSC C113821
C13: 100uF, 6,3V; C_0805_2012Metric; LCSC C141660
D2: BAT760-7; D_SOD-323; LCSC C116158
D3, D4: LTST-C191KRKT (Red); LED_0603_1608Metric; LCSC C125099
J4: PJ-002AH-SMT-TR (Barrel Jack); BarrelJack_CLIFF_FC681465S_SMT_Horizontal; Mouser Part Number 490-PJ-002AH-SMT-TR
J5: Conn_02x02_Top_Bottom; PinHeader_2x02_P2.54mm_Vertical; LCSC C492419
J6: Conn_02x02_Top_Bottom (DNP); PinHeader_2x02_P2.54mm_Vertical; LCSC C492419
L1: 10uH - SLF7032T-100M1R4-2PF; L_TDK_SLF7032; Mouser Part Number 810-SLF732100M1R42PF
R11, R12, R13, R25: 0R1; R_1210_3225Metric; LCSC C473589
R14: 5k1; R_0805_2012Metric; LCSC C204548
R15: 1M; R_0805_2012Metric; LCSC C230655
R16: 1M (DNP); R_0805_2012Metric; LCSC C230655
R17: 41,2k; R_0805_2012Metric; LCSC C204486
R18: 0R (DNP); R_0805_2012Metric; LCSC C100045
R19: 0R; R_0805_2012Metric; LCSC C100045
R20: 11,5k; R_0805_2012Metric; LCSC C228269
R21: 49R9; R_0805_2012Metric; LCSC C479104
R22: 845k; R_0805_2012Metric; LCSC C416871
R23: 261k; R_0805_2012Metric; LCSC C352236
R24: 1k5; R_0805_2012Metric; LCSC C163951
TP8: Ext Voltage 12V; TestPoint_Pad_2.0x2.0mm
TP9: 3V3; TestPoint_Pad_2.0x2.0mm
U1: LTC3111EMSEPBF; MSOP-16-1EP_3x4.039mm_P0.5mm_EP1.651x2.845mm_ThermalVias; MANUFACTURER_PART_NUMBER ltc3111emse#pbf; LCSC C684080

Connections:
+5VD: R12.2; also elsewhere on the board
+12V: R11.2, R13.2, TP8.1; also elsewhere on the board
/Espressif Developer Platform - Power/J5_5V: J5.4, R12.1
/Espressif Developer Platform - Power/J5_12V: J5.3, R11.1
/Espressif Developer Platform - Power/LT_COMP: C9.1, R17.2, U1.1 (COMP)
/Espressif Developer Platform - Power/LT_FB: C9.2, C11.2, R20.2, R22.2, R23.1, U1.2 (FB)
/Espressif Developer Platform - Power/LT_PWM: R18.2, R19.1, U1.15 (PWM/SYNC)
/Espressif Developer Platform - Power/LT_RUN: C7.2, R15.2, R16.1, U1.4 (RUN)
/Espressif Developer Platform - Power/LT_VCC: C10.2, R19.2, U1.14 (VCC)
/Espressif Developer Platform - Power/LT_VIN: C3.2, C4.1, J5.1, J5.2, R15.1, U1.5 (VIN)
GND: C3.1, C4.2, C6.2, C7.1, C10.1, C13.2, C14.1, D3.1, D4.1, J4.2, J4.3, J6.3, J6.4, R16.2, R18.1, R23.2, U1.3 (SNSGND), U1.8 (PGND_2), U1.9 (PGND_3), U1.13 (NC), U1.16 (SGND), U1.17 (PGND); also elsewhere on the board
unnamed: C5.1, L1.1, U1.6 (SW1)
unnamed: C5.2, U1.7 (BST1)
unnamed: C6.1, D2.1 (K), R13.1
unnamed: C8.1, L1.2, U1.11 (SW2)
unnamed: C8.2, U1.10 (BST2)
unnamed: C11.1, R17.1
unnamed: C12.1, R20.1
unnamed: C12.2, R21.2, R22.1
unnamed: C13.1, C14.2, R21.1, R24.2, R25.1, U1.12 (VOUT)
unnamed: D2.2 (A), J4.1, R14.2
unnamed: D3.2, R14.1
unnamed: D4.2, R24.1
VDD: J6.1, J6.2, R25.2, TP9.1; also elsewhere on the board

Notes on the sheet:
OUTPUT VOLTAGE PROGRAMMING The output voltage is set via the external resistor divider comprised of resistors Ra and Rb as show in Figures 1. The resistor divider values determine the output regulation voltage according to: VOUT = 0.8V • (1+Ra/Rb) In addition to setting the output voltage, the valu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
For 3V3 output use : Ra = 845k Rb = 261k
External Power Supply, 2.5V ... 24V
USB Power (VBUS) and external 12V are decoupled by Schottky and 0R1 so they can be connected here. Higher Voltage on either rail will feed the system
External Power
LT_VIN may be between 2V5 and 15V
Output 3V3 @ 1.5A
Connector to loop in external battery controller In normal mode connect J5.1 with J5.3 and J5.2 with J5.4 (2 Jumpers) When using an external battery controller such as Sparkfun's babysitter, open the Jumpers, connect J5.4 to the input of the controller and J5.2 to the output of the controller (=bat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
Connector to use 3V3 !! Do not feed in 3V3 here !!
3V3 System Voltage (VDD)
Footprint 7 x 7 mm
!! Check if Power on inner Pin !! !! is ok for application !!
WhirlingBits
Rb was reduced from 270k to 261k after prototype board showed 3,18V instead of 3.3V. Calculating the above formula this gives a voltage of 3.39V but should adjust output voltage in real circuitry to about 3.3V

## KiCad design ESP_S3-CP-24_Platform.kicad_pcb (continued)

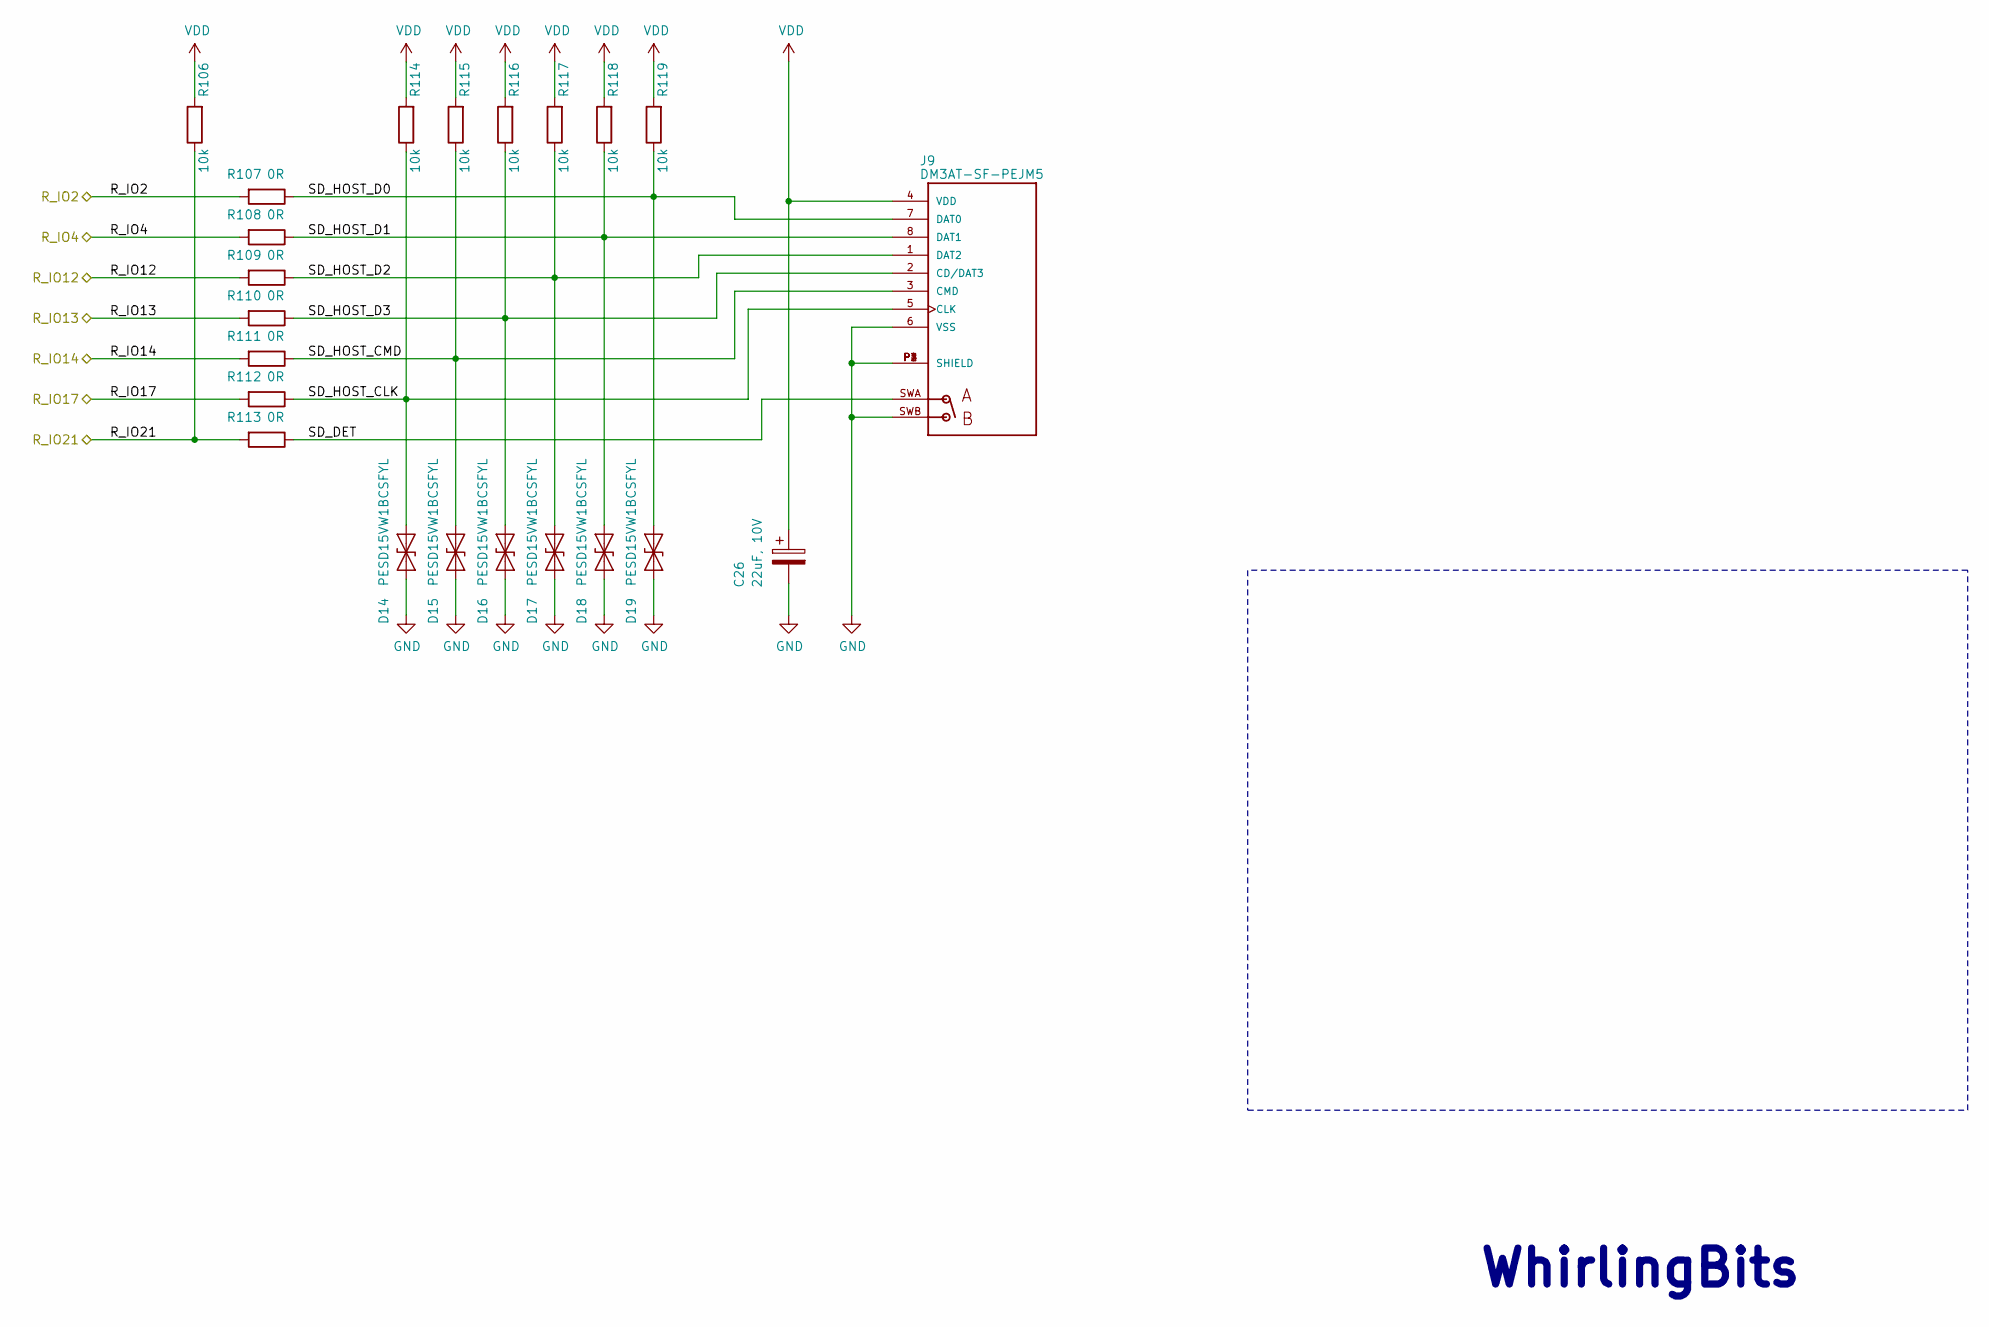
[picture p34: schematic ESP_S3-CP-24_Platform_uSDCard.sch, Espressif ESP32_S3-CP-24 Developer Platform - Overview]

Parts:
C26: 22uF, 10V; C_0805_2012Metric; Mouser 81-GRM21BD71A226ME4L
D14, D15, D16, D17, D18, D19: PESD15VW1BCSFYL; D_SOD-523; Mouser Part Number 771-PESD15VW1BCSFYL; Mouser 771-PESD15VW1BCSFYL
J9: DM3AT-SF-PEJM5; HRS_DM3AT-SF-PEJM5; LCSC C114218
R106, R114, R115, R116, R117, R118, R119: 10k; R_0805_2012Metric; LCSC C169253
R107, R108, R109, R110, R111, R112, R113: 0R; R_0805_2012Metric; LCSC C100045

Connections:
/Espressif Developer PLatform - uSDCard/SD_DET: J9.SWA, R113.1
/Espressif Developer PLatform - uSDCard/SD_HOST_CLK: D14.1 (A1), J9.5 (CLK), R112.1, R114.1
/Espressif Developer PLatform - uSDCard/SD_HOST_CMD: D15.1 (A1), J9.3 (CMD), R111.1, R115.1
/Espressif Developer PLatform - uSDCard/SD_HOST_D0: D19.1 (A1), J9.7 (DAT0), R107.1, R119.1
/Espressif Developer PLatform - uSDCard/SD_HOST_D1: D18.1 (A1), J9.8 (DAT1), R108.1, R118.1
/Espressif Developer PLatform - uSDCard/SD_HOST_D2: D17.1 (A1), J9.1 (DAT2), R109.1, R117.1
/Espressif Developer PLatform - uSDCard/SD_HOST_D3: D16.1 (A1), J9.2 (CD/DAT3), R110.1, R116.1
/R_IO2: R107.2; also elsewhere on the board
/R_IO4: R108.2; also elsewhere on the board
/R_IO12: R109.2; also elsewhere on the board
/R_IO13: R110.2; also elsewhere on the board
/R_IO14: R111.2; also elsewhere on the board
/R_IO17: R112.2; also elsewhere on the board
/R_IO21: R106.1, R113.2; also elsewhere on the board
GND: C26.2, D14.2 (A2), D15.2 (A2), D16.2 (A2), D17.2 (A2), D18.2 (A2), D19.2 (A2), J9.6 (VSS), J9.P1 (SHIELD), J9.P2 (SHIELD), J9.P3 (SHIELD), J9.P4 (SHIELD), J9.SWB; also elsewhere on the board
VDD: C26.1, J9.4 (VDD), R106.2, R114.2, R115.2, R116.2, R117.2, R118.2, R119.2; also elsewhere on the board

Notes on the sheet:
WhirlingBits

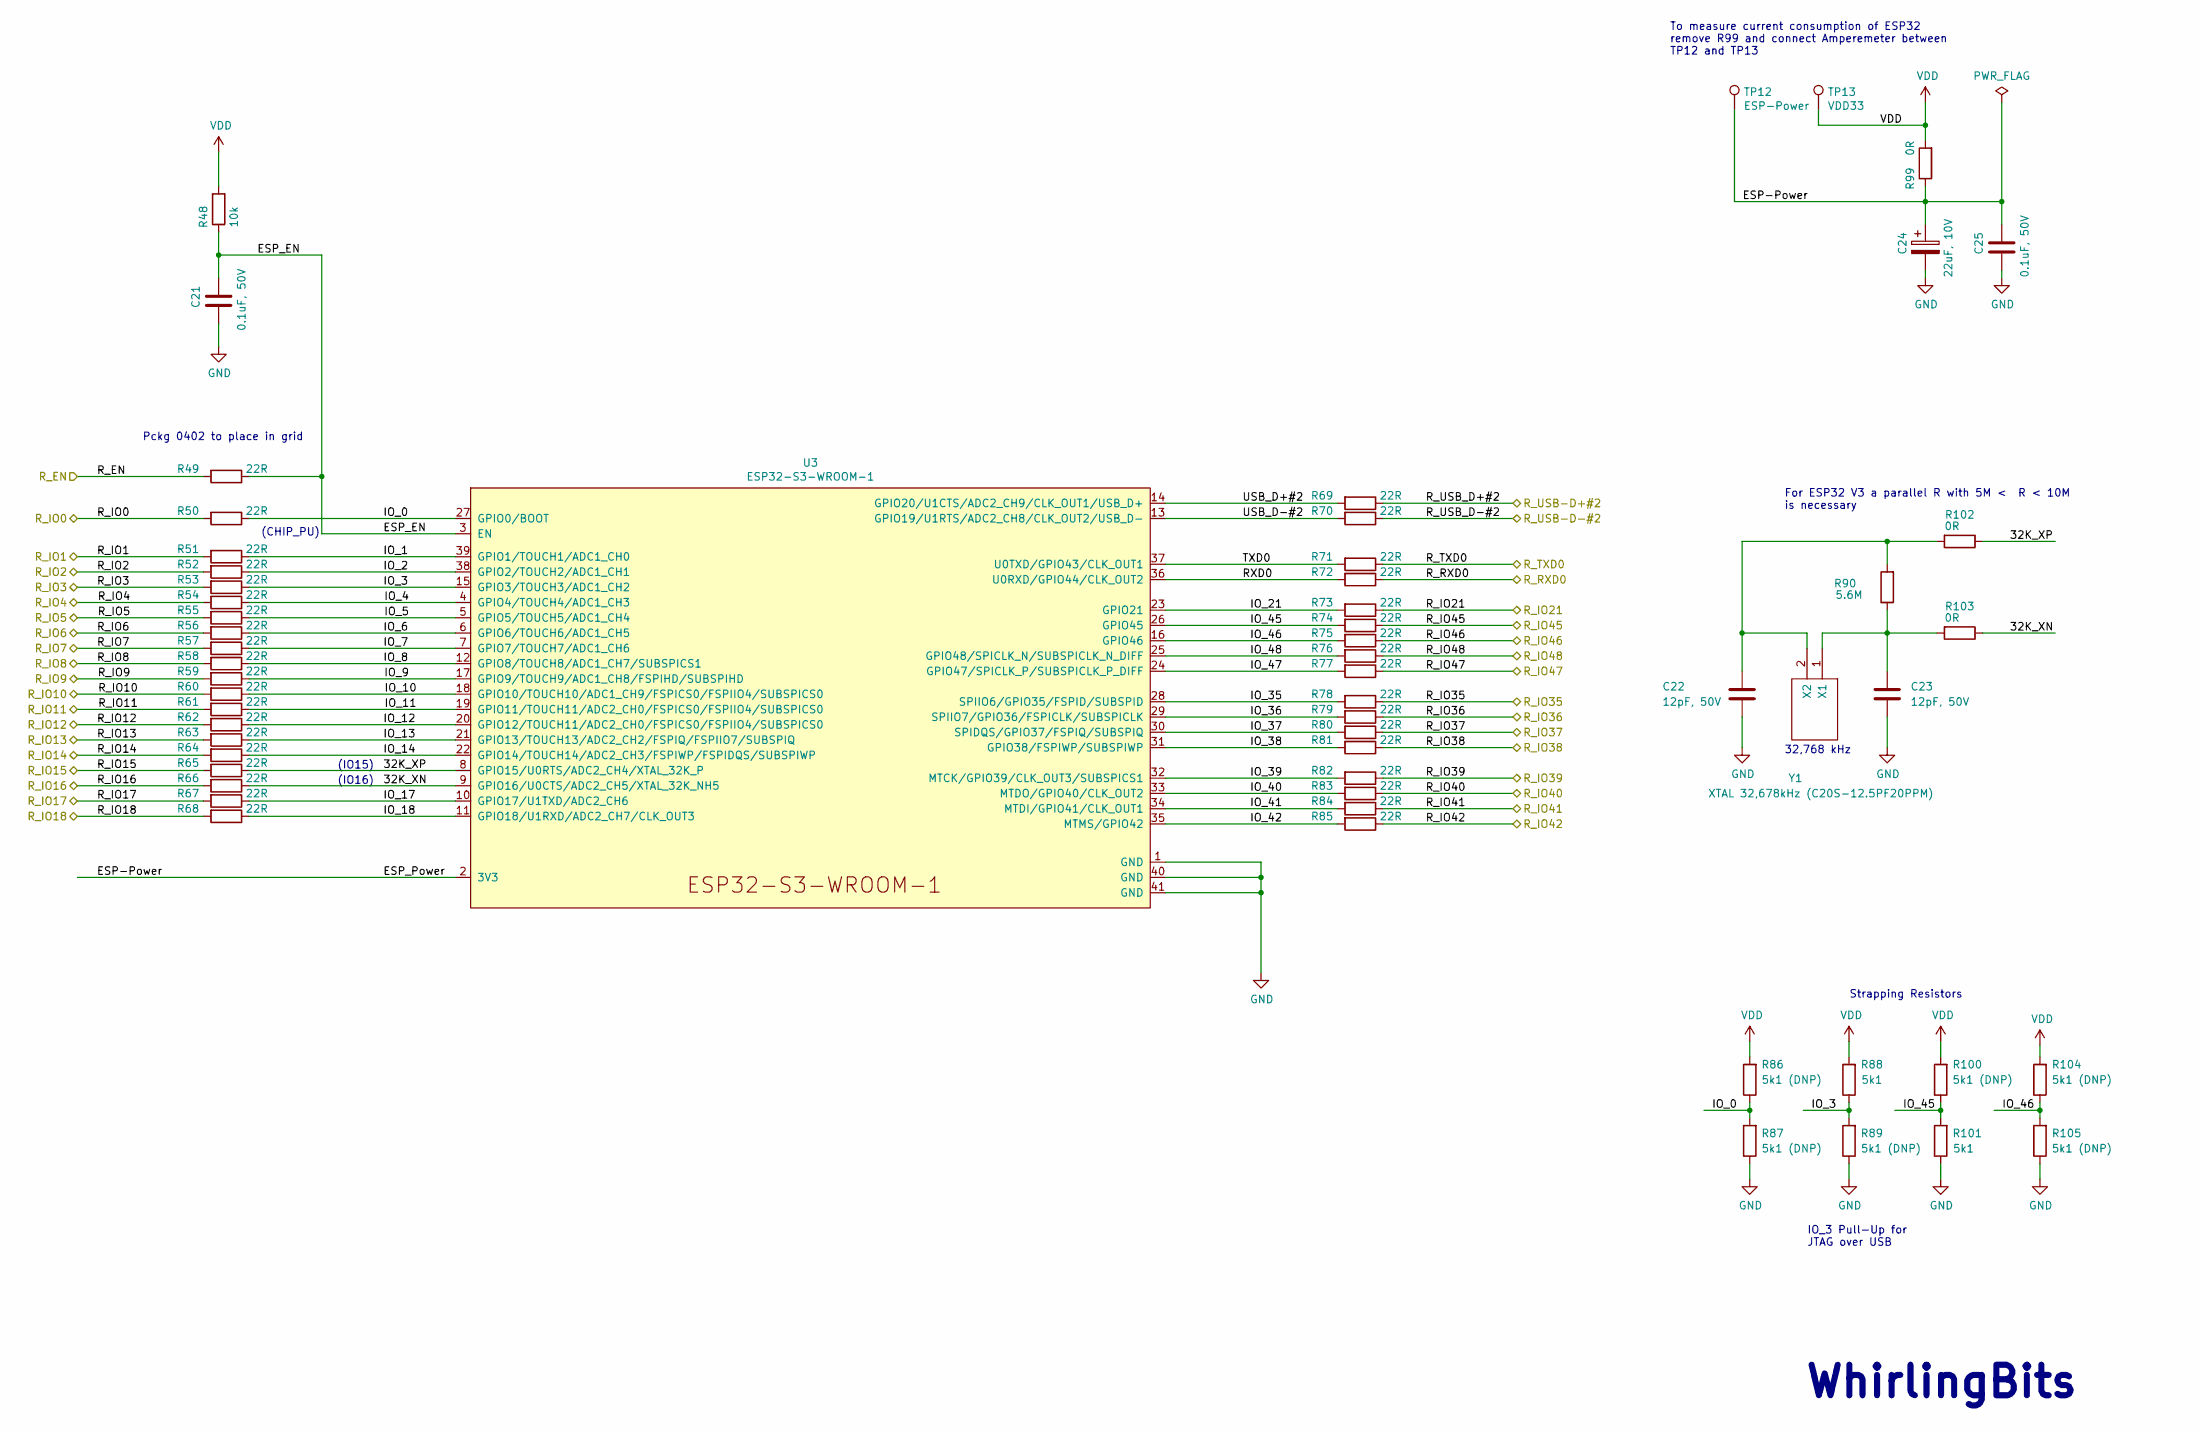
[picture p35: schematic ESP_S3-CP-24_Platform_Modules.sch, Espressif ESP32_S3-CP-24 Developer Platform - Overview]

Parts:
C21, C25: 0.1uF, 50V; C_0805_2012Metric; LCSC C161260
C22, C23: 12pF, 50V; C_0805_2012Metric; LCSC C182488
C24: 22uF, 10V; C_0805_2012Metric; Mouser 81-GRM21BD71A226ME4L
R48: 10k; R_0805_2012Metric; LCSC C169253
R49, R50, R51, R52, R53, R54, R55, R56, R57, R58, R59, R60, R61, R62, R63, R64, R65, R66, R67, R68, R69, R70, R71, R72, R73, R74, R75, R76, R77, R78, R79, R80, R81, R82, R83, R84, R85: 22R; R_0402_1005Metric; LCSC C114765
R86, R87, R89, R100, R104, R105: 5k1 (DNP); R_0805_2012Metric; LCSC C204548
R88, R101: 5k1; R_0805_2012Metric; LCSC C204548
R90: 5.6M; R_0805_2012Metric; LCSC C185285
R99, R102, R103: 0R; R_0805_2012Metric; LCSC C100045
TP12: ESP-Power; TestPoint_Pad_2.0x2.0mm
TP13: VDD33; TestPoint_Pad_2.0x2.0mm
U3: ESP32-S3-WROOM-1; LCSC C2913201
Y1: XTAL 32,678kHz (C20S-12.5PF20PPM); SC20S125PF20PPM; Manufacturer_Part_Number SC20S-12.5PF20PPM; LCSC C97603

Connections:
/Espressif Developer Platform - Modules/32K_XN: R66.1, R103.1, U3.9 (GPIO16/U0CTS/ADC2_CH5/XTAL_32K_NH5)
/Espressif Developer Platform - Modules/32K_XP: R65.1, R102.1, U3.8 (GPIO15/U0RTS/ADC2_CH4/XTAL_32K_P)
/Espressif Developer Platform - Modules/ESP-Power: C24.1, C25.1, R99.1, TP12.1, U3.2 (3V3)
/Espressif Developer Platform - Modules/ESP_EN: C21.1, R48.1, R49.1, U3.3 (EN)
/Espressif Developer Platform - Modules/IO_0: R50.1, R86.1, R87.2, U3.27 (GPIO0/BOOT)
/Espressif Developer Platform - Modules/IO_1: R51.1, U3.39 (GPIO1/TOUCH1/ADC1_CH0)
/Espressif Developer Platform - Modules/IO_2: R52.1, U3.38 (GPIO2/TOUCH2/ADC1_CH1)
/Espressif Developer Platform - Modules/IO_3: R53.1, R88.1, R89.2, U3.15 (GPIO3/TOUCH3/ADC1_CH2)
/Espressif Developer Platform - Modules/IO_4: R54.1, U3.4 (GPIO4/TOUCH4/ADC1_CH3)
/Espressif Developer Platform - Modules/IO_5: R55.1, U3.5 (GPIO5/TOUCH5/ADC1_CH4)
/Espressif Developer Platform - Modules/IO_6: R56.1, U3.6 (GPIO6/TOUCH6/ADC1_CH5)
/Espressif Developer Platform - Modules/IO_7: R57.1, U3.7 (GPIO7/TOUCH7/ADC1_CH6)
/Espressif Developer Platform - Modules/IO_8: R58.1, U3.12 (GPIO8/TOUCH8/ADC1_CH7/SUBSPICS1)
/Espressif Developer Platform - Modules/IO_9: R59.1, U3.17 (GPIO9/TOUCH9/ADC1_CH8/FSPIHD/SUBSPIHD)
/Espressif Developer Platform - Modules/IO_10: R60.1, U3.18 (GPIO10/TOUCH10/ADC1_CH9/FSPICS0/FSPIIO4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)
/Espressif Developer Platform - Modules/IO_11: R61.1, U3.19 (GPIO11/TOUCH11/ADC2_CH0/FSPICS0/FSPIIO4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)
/Espressif Developer Platform - Modules/IO_12: R62.1, U3.20 (GPIO12/TOUCH11/ADC2_CH0/FSPICS0/FSPIIO4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)
/Espressif Developer Platform - Modules/IO_13: R63.1, U3.21 (GPIO13/TOUCH13/ADC2_CH2/FSPIQ/FSPIIO7/S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)
/Espressif Developer Platform - Modules/IO_14: R64.1, U3.22 (GPIO14/TOUCH14/ADC2_CH3/FSPIWP/FSPIDQS/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)
/Espressif Developer Platform - Modules/IO_17: R67.1, U3.10 (GPIO17/U1TXD/ADC2_CH6)
/Espressif Developer Platform - Modules/IO_18: R68.1, U3.11 (GPIO18/U1RXD/ADC2_CH7/CLK_OUT3)
/Espressif Developer Platform - Modules/IO_21: R73.2, U3.23 (GPIO21)
/Espressif Developer Platform - Modules/IO_35: R78.2, U3.28 (SPIIO6/GPIO35/FSPID/SUBSPID)
/Espressif Developer Platform - Modules/IO_36: R79.2, U3.29 (SPIIO7/GPIO36/FSPICLK/SUBSPICLK)
/Espressif Developer Platform - Modules/IO_37: R80.2, U3.30 (SPIDQS/GPIO37/FSPIQ/SUBSPIQ)
/Espressif Developer Platform - Modules/IO_38: R81.2, U3.31 (GPIO38/FSPIWP/SUBSPIWP)
/Espressif Developer Platform - Modules/IO_39: R82.2, U3.32 (MTCK/GPIO39/CLK_OUT3/SUBSPICS1)
/Espressif Developer Platform - Modules/IO_40: R83.2, U3.33 (MTDO/GPIO40/CLK_OUT2)
/Espressif Developer Platform - Modules/IO_41: R84.2, U3.34 (MTDI/GPIO41/CLK_OUT1)
/Espressif Developer Platform - Modules/IO_42: R85.2, U3.35 (MTMS/GPIO42)
/Espressif Developer Platform - Modules/IO_45: R74.2, R100.1, R101.2, U3.26 (GPIO45)
/Espressif Developer Platform - Modules/IO_46: R75.2, R104.1, R105.2, U3.16 (GPIO46)
/Espressif Developer Platform - Modules/IO_47: R77.2, U3.24 (GPIO47/SPICLK_P/SUBSPICLK_P_DIFF)
/Espressif Developer Platform - Modules/IO_48: R76.2, U3.25 (GPIO48/SPICLK_N/SUBSPICLK_N_DIFF)
/Espressif Developer Platform - Modules/RXD0: R72.2, U3.36 (U0RXD/GPIO44/CLK_OUT2)
/Espressif Developer Platform - Modules/TXD0: R71.2, U3.37 (U0TXD/GPIO43/CLK_OUT1)
/Espressif Developer Platform - Modules/USB_D+#2: R69.2, U3.14 (GPIO20/U1CTS/ADC2_CH9/CLK_OUT1/USB_D+)
/Espressif Developer Platform - Modules/USB_D-#2: R70.2, U3.13 (GPIO19/U1RTS/ADC2_CH8/CLK_OUT2/USB_D-)
/R_EN: R49.2; also elsewhere on the board
/R_IO0: R50.2; also elsewhere on the board
/R_IO1: R51.2; also elsewhere on the board
/R_IO2: R52.2; also elsewhere on the board
/R_IO3: R53.2; also elsewhere on the board
/R_IO4: R54.2; also elsewhere on the board
/R_IO5: R55.2; also elsewhere on the board
/R_IO6: R56.2; also elsewhere on the board
/R_IO7: R57.2; also elsewhere on the board
/R_IO8: R58.2; also elsewhere on the board
/R_IO9: R59.2; also elsewhere on the board
/R_IO10: R60.2; also elsewhere on the board
/R_IO11: R61.2; also elsewhere on the board
/R_IO12: R62.2; also elsewhere on the board
/R_IO13: R63.2; also elsewhere on the board
/R_IO14: R64.2; also elsewhere on the board
/R_IO15: R65.2; also elsewhere on the board
/R_IO16: R66.2; also elsewhere on the board
/R_IO17: R67.2; also elsewhere on the board
/R_IO18: R68.2; also elsewhere on the board
/R_IO21: R73.1; also elsewhere on the board
/R_IO35: R78.1; also elsewhere on the board
/R_IO36: R79.1; also elsewhere on the board
/R_IO37: R80.1; also elsewhere on the board
/R_IO38: R81.1; also elsewhere on the board
/R_IO39: R82.1; also elsewhere on the board
/R_IO40: R83.1; also elsewhere on the board
/R_IO41: R84.1; also elsewhere on the board
/R_IO42: R85.1; also elsewhere on the board
/R_IO45: R74.1; also elsewhere on the board
/R_IO46: R75.1; also elsewhere on the board
/R_IO47: R77.1; also elsewhere on the board
/R_IO48: R76.1; also elsewhere on the board
/R_RXD0: R72.1; also elsewhere on the board
/R_TXD0: R71.1; also elsewhere on the board
/R_USB-D+#2: R69.1; also elsewhere on the board
/R_USB-D-#2: R70.1; also elsewhere on the board
GND: C21.2, C22.2, C23.2, C24.2, C25.2, R87.1, R89.1, R101.1, R105.1, U3.1 (GND), U3.40 (GND), U3.41 (GND); also elsewhere on the board
unnamed: C22.1, R90.2, R102.2, Y1.2 (X2)
unnamed: C23.1, R90.1, R103.2, Y1.1 (X1)
VDD: R48.2, R86.2, R88.2, R99.2, R100.2, R104.2, TP13.1; also elsewhere on the board

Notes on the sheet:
To measure current consumption of ESP32 remove R99 and connect Amperemeter between TP12 and TP13
Strapping Resistors
For ESP32 V3 a parallel R with 5M < R < 10M is necessary
Pckg 0402 to place in grid
32,768 kHz
(IO15)
(IO16)
(CHIP_PU)
IO_3 Pull-Up for JTAG over USB
WhirlingBits

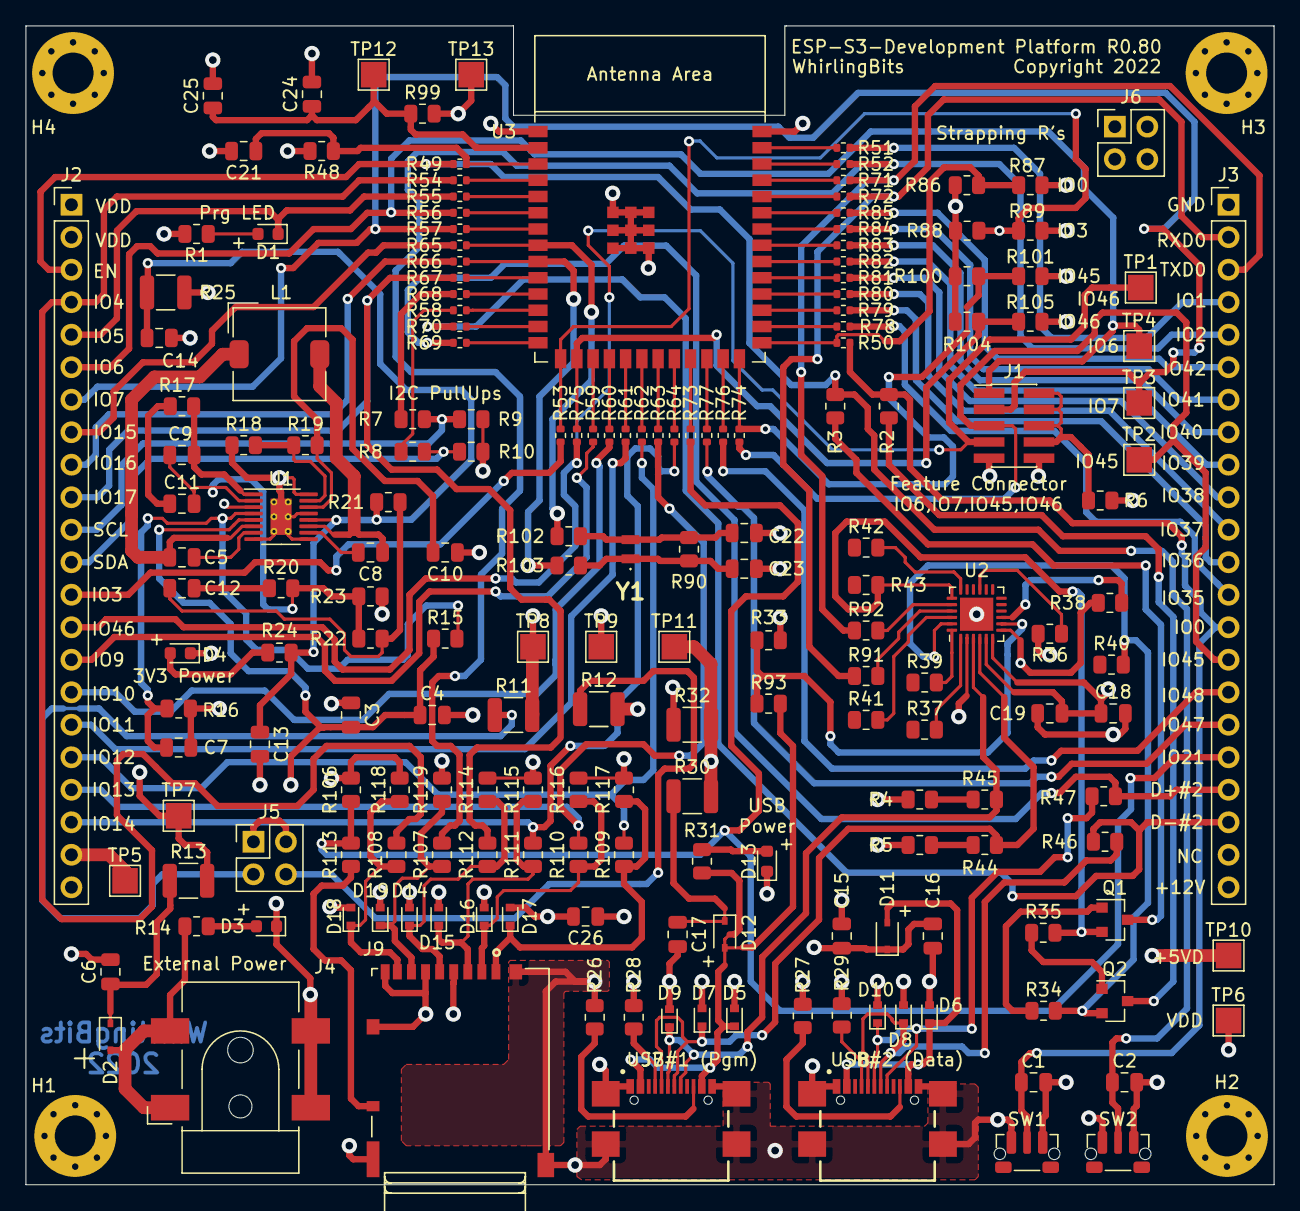
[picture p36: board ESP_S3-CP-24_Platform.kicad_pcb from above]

Board: 4 copper layers, 97.5 x 90.6 mm, 193 parts (0 on the bottom side), 142 nets.

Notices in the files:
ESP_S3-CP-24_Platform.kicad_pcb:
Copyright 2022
